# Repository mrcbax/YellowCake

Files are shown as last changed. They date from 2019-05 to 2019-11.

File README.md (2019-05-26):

YellowCake Logo

# YellowCake

YellowCake is a UMW CPSC 491 project to create an open source, inexpensive, small footprint, single board, POSIX computer. YellowCake will be similar to a Raspberry Pi. The primary goal of the YellowCake project is learning. A secondary goal is to create a product that is used by others.

The members of the YellowCake team are the following.
- Gusty Cooper - faculty sponsor
- Chad Baxter - student researcher
- Collin Mistr - student researcher

Gusty is an experienced software developer and systems engineer. Chad and Collin are talented computer science students with lots of experience in electronic board design. They have designed several boards that fix problems in various MacBook computers. Their design solutions included board layout and subsequent manufacture by a foundry. Collin and Chad are selling their MacBook solutions on Ebay. A few of of their solutions are described at: 

- https://computeco.de/DyingLight
- https://computeco.de/MuxHat

## YellowCake Executive Summary

YellowCake is a research project to create an open source, single board computer similar to a Raspberry Pi. Chad and Collin will learn the fundamentals of building a computer, which include selecting a form factor of the board, selecting electronic components for a computer, designing communication among components, layout components on the board, printing the board, assembling a computer on the board, testing the computer, and establishing a LINUX operating system on the computer. The following is a picture of a Raspberry Pi single board computer.

## YellowCake Goals

YellowCake is a three credit CPSC 491, which occurs during Fall 2019. The goals for YellowCake are the following.
- Provide an environment in which Chad and Collin can significantly increase their CPSC skills and knowledge as related to computer architecture, design of single board computers, integration of electronics on single board computers, testing single board computers, and hosting and OS on single board computers.
- Complete the design YellowCake - the design is to be documented as open source.
- Complete the YellowCake board layout in a manufacturing format using the board CAD software KiCad: http://kicad-pcb.org/ - the layout is to be documented as open source.
- Complete a prototype of YellowCake - follow the process in YellowCake Design and Development Process to implement a prototype that demonstrates the design.

## YellowCake Prework

During Spring 2019, the YellowCake team will meet periodically to discuss the project, make preliminary decisions, define the parameters for CPSC 491 YellowCake, and submit funding requests. 
YellowCake Design Parameters
We have begun preliminary design, creating various design parameters. Design parameters are subject to change. The design parameters defined thus far are the following.
- YellowCake board.
  - Footprint will be small similar in size to Raspberry Pi.
  - YellowCake board footprint will adhere to a standard. The following are candidates.
     - PCI / 104 - Express:  https://pc104.org/hardware-specifications/pc104/
     - Intel NUC - https://www.intel.com/content/www/us/en/support/articles/000005545/mini-pcs.html
     - Pico-ITX - https://www.viatech.com/en/boards/pico-itx/ 
- YellowCake CPU Selection. We have had various ideas for YellowCake CPU. The primary option is to use an Intel family chip, which provide a large selection of LINUX operating systems. A design consideration is to select a CPU chip that is approximately $50. The following link shows several Intel options.
https://www.mouser.com/Semiconductors/Embedded-Processors-Controllers/CPU-Central-Processing-Units/_/N-ba96s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|0

Some specific ideas we have considered are the following:
- Idea 1: Intel M series. The availability of Intel M chipsets may make the cost prohibitive.
- Idea 3: Intel Atom
- Idea 2: RISC-V. The availability of RISC-V chipsets may make the cost prohibitive.

YellowCake main memory. 
- Will be LPDDR3. DDR4 is newer and faster, but it costs significantly more than DDR3.

YellowCake secondary storage
- Will be eMMC technology.

YellowCake primary bus connecting CPU, Memory, and other devices 
- Will be determined.
YellowCake I/O
- USB-C NO: Atom does not support USB-C.YellowCake will include 1 USB-C port (if cpu choice supports it).
- USB-3:YellowCake will include 2 USB-3 ports.
- HDMI: YellowCake will include 1 HDMI port.
- WiFI: YellowCake will include wireless (a/b/g/n).
- Bluetooth: YellowCake will include bluetooth.

## YellowCake Design and Development Process

The YellowCake high-level design and development process (to be practiced in Fall 2019) consists of several cycles of design, produce, and test. The cycles continue until the final YellowCake product is created or funding diminishes. More details of design, produce, and test are the following.
- Design a rendition of the board.
- Submit the design to a foundry.
- Receive the board.
- Apply the components to the board.
- Test the board. 

## YellowCake Budget

We expect up to four iterations of the design process to achieve the final design. Total cost of the project is estimated to be $1000, which is $250 per design iteration. The detailed estimated cost of each design iteration is as follows.
- $75 - pay foundry to print the board.
- $50 - CPU SOC
- $25 - Memory components (BGA LPDDR3 4GB)
- $100 - support components (resistors, capacitors, connectors, ICs, ports,
headers, etc.)

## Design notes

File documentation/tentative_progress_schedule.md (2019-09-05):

# YellowCake Schedule

## September

- 9/4 - Initial Parts List
- 9/6 2pm - Visit Colonial Circuits
- 9/11 - Parts Ordered
- 9/25 - Begin writing report
- 9/30 - Initial Board Layout submitted

## October

- 10/9 - Parts placed on initial board layout
- 10/9 - Trouble shoot initial board and parts
- 10/16 - Second Board Layout submitted
- 10/23 - Update report
- 10/20 - Parts placed on second board layout

## November

- 11/6 - Trouble shoot second board and parts
- 11/8 - Third board layout submitted
- 11/13 - Finalize report
- 11/20 - Parts placed on third board layout
- 11/27 - Trouble shoot third board and parts

## December

- 12/4 - OS Running

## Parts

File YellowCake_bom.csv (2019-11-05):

Reference | Quantity | Value | Footprint | Datasheet | Type | Rating | Price Per Unit | Net | Notes
C1 C14 C11 C12 C9 C18 C30 C21 C34 C55 C58 C73 C75 C60 C67 C69 C74 C68 C72 C71 C70 C83 | 22 | 0.1uF | Capacitor_SMD:C_0603_1608Metric | ~ |  |  | $0.01 | $0.22
C22 C19 | 2 | 330pF | Capacitor_SMD:C_0603_1608Metric | ~ |  |  | $0.01 | $0.02
C23 C20 | 2 | 0.01uF | Capacitor_SMD:C_0603_1608Metric | ~ |  |  | $0.01 | $0.02
C25 | 1 | 470pF | Capacitor_SMD:C_0603_1608Metric | ~ |  |  | $0.01 | $0.01
C26 | 1 | 68pF | Capacitor_SMD:C_0603_1608Metric | ~ |  |  | $0.01 | $0.01
C27 | 1 | 220pF | Capacitor_SMD:C_0603_1608Metric | ~ |  |  | $0.01 | $0.01
C28 C24 | 2 | 560pF | Capacitor_SMD:C_0603_1608Metric | ~ |  |  | $0.01 | $0.02
C29 | 1 | 33pF | Capacitor_SMD:C_0603_1608Metric | ~ |  |  | $0.01 | $0.01
C32 C35 C37 C61 C66 | 5 | 1.0uF | Capacitor_SMD:C_0603_1608Metric | ~ |  |  | $0.01 | $0.05
C33 C17 C31 C16 | 4 | 1000pF | Capacitor_SMD:C_0603_1608Metric | ~ |  |  | $0.01 | $0.04
C39 C38 C36 C64 | 4 | 0.22uF | Capacitor_SMD:C_0603_1608Metric | ~ |  |  | $0.01 | $0.04
C4 C5 | 2 | 2.2uF | Capacitor_SMD:C_0603_1608Metric | ~ | CERM_LESR |  | $0.05 | $0.10
C41 C40 | 2 | 2200pF | Capacitor_SMD:C_0603_1608Metric | ~ |  |  | $0.01 | $0.02
C43 C42 | 2 | 0.047uF | Capacitor_SMD:C_0603_1608Metric | ~ |  |  | $0.01 | $0.02
C47 C45 C46 C44 C49 C48 | 6 | 0.033uF | Capacitor_SMD:C_0603_1608Metric | ~ |  |  | $0.01 | $0.06
C50 | 1 | 0.1uF |  | ~ |  |  | $0.01 | $0.01
C51 | 1 | 4.7uF |  | ~ |  |  | $0.01 | $0.01
C52 C53 | 2 | 10uF |  | ~ |  |  | $0.01 | $0.02
C54 | 1 | 8200pF | Resistor_SMD:R_0603_1608Metric | ~ |  | 1000v | $0.01 | $0.01
C56 C57 C59 C62 C63 C76 C77 C79 C81 C82 | 10 | 22uF | Capacitor_SMD:C_0603_1608Metric | ~ |  |  | $0.01 | $0.10
C6 C2 C3 | 3 | 1uF | Capacitor_SMD:C_0603_1608Metric | ~ |  |  | $0.01 | $0.03
C7 C10 | 2 | 10uF | Capacitor_Tantalum_SMD:CP_EIA-2012-15_AVX-P | ~ | TANT |  | $0.05 | $0.10
C8 C13 C15 C78 C80 C65 | 6 | 10uF | Capacitor_SMD:C_0603_1608Metric | ~ |  |  | $0.01 | $0.06
D1 | 1 | BAT54A | Package_TO_SOT_SMD:SOT-23 | http://www.diodes.com/_files/datasheets/ds11005.pdf |  |  | $0.10 | $0.10
D2 D3 | 2 | BAV99S | Package_TO_SOT_SMD:SOT-363_SC-70-6 | https://assets.nexperia.com/documents/data-sheet/BAV99_SER.pdf |  |  | $0.40 | $0.80
J1 | 1 | HDMI_A |  | https://en.wikipedia.org/wiki/HDMI |  |  | $0.00 | $0.00 | Purchased
J2 | 1 | SODIMM-200 |  |  |  |  | $0.00 | $0.00 | Purchased
J3 | 1 | Micro_SD_Card |  | http://katalog.we-online.de/em/datasheet/693072010801.pdf |  |  | $0.00 | $0.00 | Purchased
J4 | 1 | Conn_Coaxial_Power |  | ~ |  |  | $0.00 | $0.00 | Purchased
L1 | 1 | 220Ohm | Inductor_SMD:L_0603_1608Metric | ~ |  |  | $0.05 | $0.05
L2 | 1 | FB_220R_2.2A | Inductor_SMD:L_0603_1608Metric | ~ |  |  | $0.05 | $0.05
L5 L6 L3 L4 | 4 | FB_120R_3A | Inductor_SMD:L_0603_1608Metric | ~ |  |  | $0.05 | $0.20
L7 | 1 | PIND-2.2U-8A | Inductor_SMD:L_0603_1608Metric | ~ |  |  | $0.05 | $0.05
R1 R2 | 2 | 2.2kOhm | Resistor_SMD:R_0603_1608Metric | ~ |  |  | $0.01 | $0.02
R13 | 1 | 2.7KOhm | Resistor_SMD:R_0603_1608Metric | ~ |  |  | $0.01 | $0.01
R14 R15 R11 R12 | 4 | 10Ohm | Resistor_SMD:R_0603_1608Metric | ~ |  |  | $0.01 | $0.04
R16 | 1 | 2.32KOhm | Resistor_SMD:R_0603_1608Metric | ~ |  |  | $0.01 | $0.01
R18 | 1 | 2.43KOhm | Resistor_SMD:R_0603_1608Metric | ~ |  |  | $0.01 | $0.01
R19 R17 | 2 | 200Ohm | Resistor_SMD:R_0603_1608Metric | ~ |  |  | $0.01 | $0.02
R21 | 1 | 2.21KOhm | Resistor_SMD:R_0603_1608Metric | ~ |  |  | $0.01 | $0.01
R23 R20 R27 | 3 | 80.6KOhm | Resistor_SMD:R_0603_1608Metric | ~ |  |  | $0.01 | $0.03
R25 R24 R22 | 3 | 69.8Ohm | Resistor_SMD:R_0603_1608Metric | ~ |  |  | $0.01 | $0.03
R26 | 1 | 169KOhm | Resistor_SMD:R_0603_1608Metric | ~ |  |  | $0.01 | $0.01
R30 R28 | 2 | 1.91KOhm | Resistor_SMD:R_0603_1608Metric | ~ |  |  | $0.01 | $0.02
R31 R29 | 2 | 6.98KOhm | Resistor_SMD:R_0603_1608Metric | ~ |  |  | $0.01 | $0.02
R33 | 1 | 16.9Ohm | Resistor_SMD:R_0603_1608Metric | ~ |  |  | $0.01 | $0.01
R34 R32 R36 R9 R10 R7 R8 R43 R42 R38 R39 | 11 | 0Ohm | Resistor_SMD:R_0603_1608Metric | ~ |  |  | $0.01 | $0.11
R35 | 1 | 20Ohm | Resistor_SMD:R_0603_1608Metric | ~ |  |  | $0.01 | $0.01
R37 | 1 | 1KOhm | Resistor_SMD:R_0603_1608Metric | ~ |  |  | $0.01 | $0.01
R4 R3 R75 R74 R73 R72 R71 R70 | 8 | 33Ohm | Resistor_SMD:R_0603_1608Metric | ~ |  |  | $0.01 | $0.08
R40 | 1 | 1Ohm | Resistor_SMD:R_0603_1608Metric | ~ |  |  | $0.01 | $0.01
R41 R48 | 2 | 18.7KOhm | Resistor_SMD:R_0603_1608Metric | ~ |  |  | $0.01 | $0.02
R44 R47 | 2 | 3.83KOhm | Resistor_SMD:R_0603_1608Metric | ~ |  |  | $0.01 | $0.02
R45 R46 | 2 | NTC-470KOhm | Resistor_SMD:R_0603_1608Metric | ~ |  |  | $0.01 | $0.02
R5 | 1 | 37.4KOhm | Resistor_SMD:R_0603_1608Metric | ~ |  |  | $0.01 | $0.01
R50 R49 | 2 | 649Ohm | Resistor_SMD:R_0603_1608Metric | ~ |  |  | $0.01 | $0.02
R51 | 1 | 2.67KOhm | Resistor_SMD:R_0603_1608Metric | ~ |  |  | $0.01 | $0.01
R54 R53 | 2 | 11KOhm | Resistor_SMD:R_0603_1608Metric | ~ |  |  | $0.01 | $0.02
R56 | 1 | 2.55KOhm | Resistor_SMD:R_0603_1608Metric | ~ |  |  | $0.01 | $0.01
R57 R52 | 2 | 2.61KOhm | Resistor_SMD:R_0603_1608Metric | ~ |  |  | $0.01 | $0.02
R58 R55 | 2 | NTC-10KOhm | Resistor_SMD:R_0603_1608Metric | ~ |  |  | $0.01 | $0.02
R59 R60 R67 | 3 | 0Ohm | Resistor_SMD:R_0603_1608Metric | ~ |  |  | $0.01 | $0.03
R6 | 1 | 12.1KOhm | Resistor_SMD:R_0603_1608Metric | ~ |  |  | $0.01 | $0.01
R61 | 1 | 2.2KOhm | Resistor_SMD:R_0603_1608Metric | ~ |  |  | $0.01 | $0.01
R62 | 1 | 2.2KOkm | Resistor_SMD:R_0603_1608Metric | ~ |  |  | $0.01 | $0.01
R63 R64 R65 R66 R68 | 5 | 10KOhm | Resistor_SMD:R_0603_1608Metric | ~ |  |  | $0.01 | $0.05
R69 | 1 | 100KOhm | Resistor_SMD:R_0603_1608Metric | ~ |  |  | $0.01 | $0.01
R76 R77 R78 R79 R80 R81 R87 R85 | 8 | 100KOhm | Resistor_SMD:R_0603_1608Metric | ~ |  |  | $0.01 | $0.08
R83 | 1 | 2.2Ohms | Resistor_SMD:R_0603_1608Metric | ~ |  |  | $0.01 | $0.01
R84 R82 | 2 | 499KOhm | Resistor_SMD:R_0603_1608Metric | ~ |  |  | $0.01 | $0.02
R86 | 1 | 4.7Ohm | Resistor_SMD:R_0603_1608Metric | ~ |  |  | $0.01 | $0.01
U1 | 1 | CS4207-CNZ | CIR-QFN-48_6X6 |  |  |  | $10.00 | $10.00
U10 | 1 | atom_F |  |  |  |  | $0.00 | $0.00 | Purchased
U11 | 1 | atom_G |  |  |  |  | $0.00 | $0.00 | Purchased
U12 | 1 | atom_H |  |  |  |  | $0.00 | $0.00 | Purchased
U13 | 1 | atom_I |  |  |  |  | $0.00 | $0.00 | Purchased
U14 | 1 | atom_J |  |  |  |  | $0.00 | $0.00 | Purchased
U15 | 1 | atom_K |  |  |  |  | $0.00 | $0.00 | Purchased
U16 | 1 | atom_L |  |  |  |  | $0.00 | $0.00 | Purchased
U17 | 1 | NB670 |  |  |  |  | $3.00 | $3.00
U18 | 1 | IRF9321 |  |  |  |  | $4.00 | $4.00
U2 | 1 | ISL95837HRZ-T | Package_DFN_QFN:QFN-40-1EP_6x6mm_P0.5mm_EP4.6x4.6mm |  |  |  | $4.00 | $4.00
U3 | 1 | TPD12S016PWR | PW24 |  |  |  | $2.00 | $2.00
U4 | 1 | TPD6E001RSER | TPD6E001RSER:TPD6E001RSER |  |  |  | $0.60 | $0.60
U5 | 1 | atom_A |  |  |  |  | $0.00 | $0.00 | Purchased
U6 | 1 | atom_B |  |  |  |  | $0.00 | $0.00 | Purchased
U7 | 1 | atom_C |  |  |  |  | $0.00 | $0.00 | Purchased
U8 | 1 | atom_D |  |  |  |  | $0.00 | $0.00 | Purchased
U9 | 1 | atom_E |  |  |  |  | $0.00 | $0.00 | Purchased
_ | _ | _ | _ | _ | Overrun Buffer | $20.00 | Total | $46.71

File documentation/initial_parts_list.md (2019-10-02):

# Initial Parts List

## Main Components

- [x2] Atom e3826 or equivalent: [https://www.mouser.com/ProductDetail/Intel/FH8065301542213-S-R1RC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](https://www.mouser.com/ProductDetail/Intel/FH8065301542213-S-R1RC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)
- [x8] SODIMM slots: [https://www.mouser.com/ProductDetail/TE-Connectivity-AMP/2-2013022-1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](https://www.mouser.com/ProductDetail/TE-Connectivity-AMP/2-2013022-1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)
- [x4] Micro-SD slots: [https://www.mouser.com/ProductDetail/Molex/104031-0811?qs=sGAEpiMZZMvlX3nhDDO4APpvzJC5rjSIQk8rK5oWGmY%3D](https://www.mouser.com/ProductDetail/Molex/104031-0811?qs=sGAEpiMZZMvlX3nhDDO4APpvzJC5rjSIQk8rK5oWGmY%3D)
- [x4] PCI/104 Express headers: [https://www.mouser.com/ProductDetail/Samtec/ASP-129637-03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](https://www.mouser.com/ProductDetail/Samtec/ASP-129637-03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)
- [x2] intel hdaudio codec [https://www.mouser.com/ProductDetail/Cirrus-Logic/CS4207-CNZ?qs=sGAEpiMZZMtq3QB8qGen7SBsPebhPp2DIspEOUgddMo%3D](https://www.mouser.com/ProductDetail/Cirrus-Logic/CS4207-CNZ?qs=sGAEpiMZZMtq3QB8qGen7SBsPebhPp2DIspEOUgddMo%3D)

## I/O Components

- [x4] THT HDMI ports: [https://www.mouser.com/ProductDetail/Amphenol-FCI/10029449-111RLF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](https://www.mouser.com/ProductDetail/Amphenol-FCI/10029449-111RLF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)
- [x4] THT Double USB ports: [https://www.mouser.com/ProductDetail/Kycon/KUSBX-AS1N9-1-BL30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](https://www.mouser.com/ProductDetail/Kycon/KUSBX-AS1N9-1-BL30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)
- [x4] THT Ethernet ports: [https://www.mouser.com/ProductDetail/Amphenol-Commercial-Products/RJE03-188-0110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](https://www.mouser.com/ProductDetail/Amphenol-Commercial-Products/RJE03-188-0110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)
- [x4] THT Audio jack: (HAVE)
- [x4] THT DC plugs: [https://www.mouser.com/ProductDetail/CUI/PJ-079BH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](https://www.mouser.com/ProductDetail/CUI/PJ-079BH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)
- [x4] THT eSATA ports: [https://www.mouser.com/ProductDetail/Amphenol-Commercial-Products/G091231304LF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](https://www.mouser.com/ProductDetail/Amphenol-Commercial-Products/G091231304LF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)

## Passive Components (On hold for datasheet reading).

- [x100] 0604m 0Ohm resistors

TOTALS: $223.14 + $9.79 S+H

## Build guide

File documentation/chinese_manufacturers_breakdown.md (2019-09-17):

# Chinese Manufacturers Breakdown

## JLCPCB

JLCPCB is a PCB manufacturing facility based in China.

Given the specifications of our board design, they have quoted us a price as follows:

$28 for board production (run of 5, which is their minimum quantity)
$17 for shipping via DHL

Lead time: up to 12 hours
Production time: 3-4 days
Shipping time: 2-4 business days via DHL

Payments can be made with all major cards (Visa, MasterCard, and AmEx), as well as PayPal and JLC’s custom “JPay”.

More info can be found at https://support.jlcpcb.com

## PCBWay

PCBWay.com offers near identical technical abilities as JLCPCB.com. Where they differ is in pricing and special offers. Through PCBWay it is possible to get a discount if your project is open source. The catch to this is that they will determine the discount at time of purchase.

For our planned design PCBWay will charge the following:

$49 for board production.
$17 for shipping.
($66 total)

Production lead time: 12 hours
Production time: 48 hours
Shipping time: 2-4 days (highly variable sometimes as much as a week)

They take payment from all major cards (Visa, Mastercard, Amex). They also accept payment from PayPal, AliPay, OKPay, and other popular online payment options.

We personally have seen discounts in the order of 10-15% off by "partnering with pcbway" on an open source project.

More info can be found at the following links:

https://www.pcbway.com/about.html About the company.
https://www.pcbway.com/sponsor.html Discount for student sponsorships.

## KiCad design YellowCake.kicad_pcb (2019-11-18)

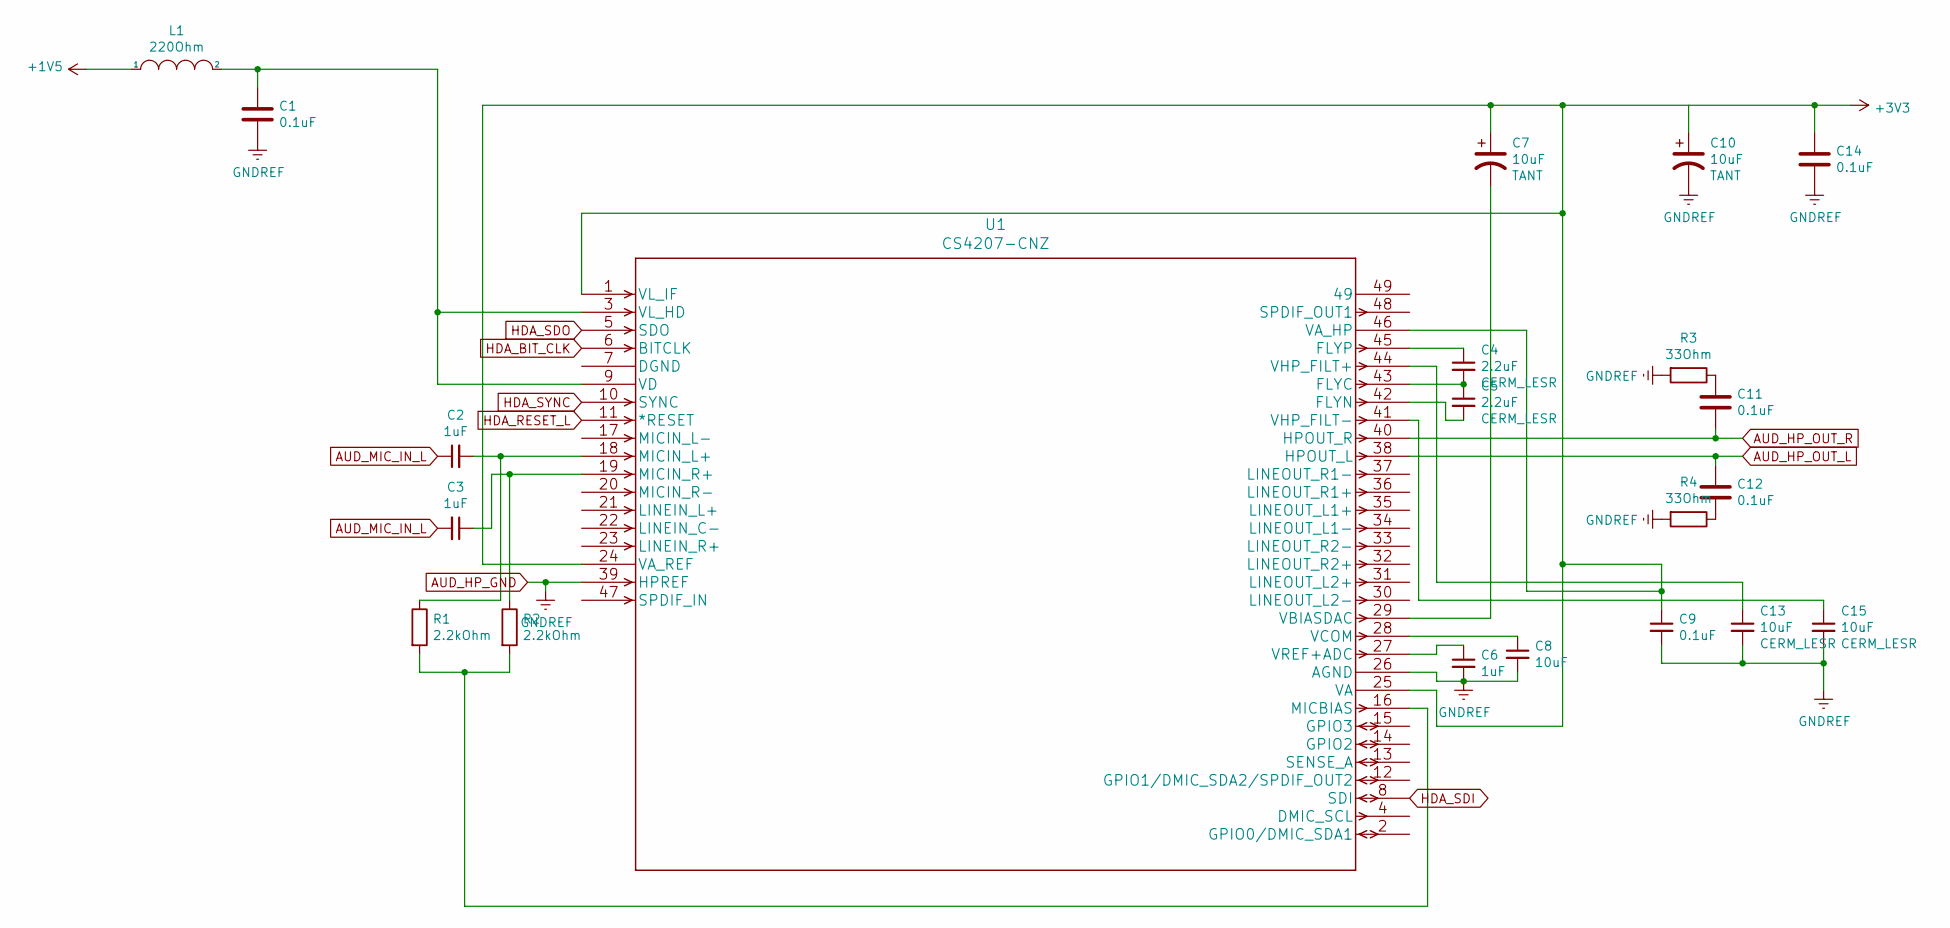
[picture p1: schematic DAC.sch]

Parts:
C1, C9, C11, C12, C14: 0.1uF; C_0603_1608Metric
C2, C3, C6: 1uF; C_0603_1608Metric
C4, C5: 2.2uF; C_0603_1608Metric
C7, C10: 10uF; CP_EIA-2012-15_AVX-P
C8, C13, C15: 10uF; C_0603_1608Metric
L1: 220Ohm; L_0603_1608Metric
R1, R2: 2.2kOhm; R_0603_1608Metric
R3, R4: 33Ohm; R_0603_1608Metric
U1: CS4207-CNZ

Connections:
+1V5: L1.1
+3V3: C7.1, C9.1, C14.1, U1.1 (VL_IF), U1.24 (VA_REF), U1.25 (VA), U1.46 (VA_HP); also elsewhere on the board
AUD_HP_GND: C1.2, C6.2, C8.2, C9.2, C10.2, C13.2, C14.2, C15.2, R3.2, R4.2, U1.26 (AGND), U1.39 (HPREF)
AUD_HP_OUT_L: C12.1, U1.38 (HPOUT_L)
AUD_HP_OUT_R: C11.2, U1.40 (HPOUT_R)
AUD_MIC_IN_L: C2.1, C3.2
HDA_BIT_CLK: U1.6 (BITCLK)
HDA_RESET_L: U1.11 (*RESET)
HDA_SDI: U1.8 (SDI)
HDA_SDO: U1.5 (SDO)
HDA_SYNC: U1.10 (SYNC)
unnamed: C1.1, L1.2, U1.3 (VL_HD), U1.9 (VD)
unnamed: C2.2, R1.1, U1.18 (MICIN_L+)
unnamed: C3.1, R2.1, U1.19 (MICIN_R+)
unnamed: C4.1, U1.45 (FLYP)
unnamed: C4.2, C5.1, U1.43 (FLYC)
unnamed: C5.2, U1.42 (FLYN)
unnamed: C6.1, U1.27 (VREF+ADC)
unnamed: C7.2, U1.29 (VBIASDAC)
unnamed: C8.1, U1.28 (VCOM)
unnamed: C11.1, R3.1
unnamed: C12.2, R4.1
unnamed: C13.1, U1.44 (VHP_FILT+)
unnamed: C15.1, U1.41 (VHP_FILT-)
unnamed: R1.2, R2.2, U1.16 (MICBIAS)

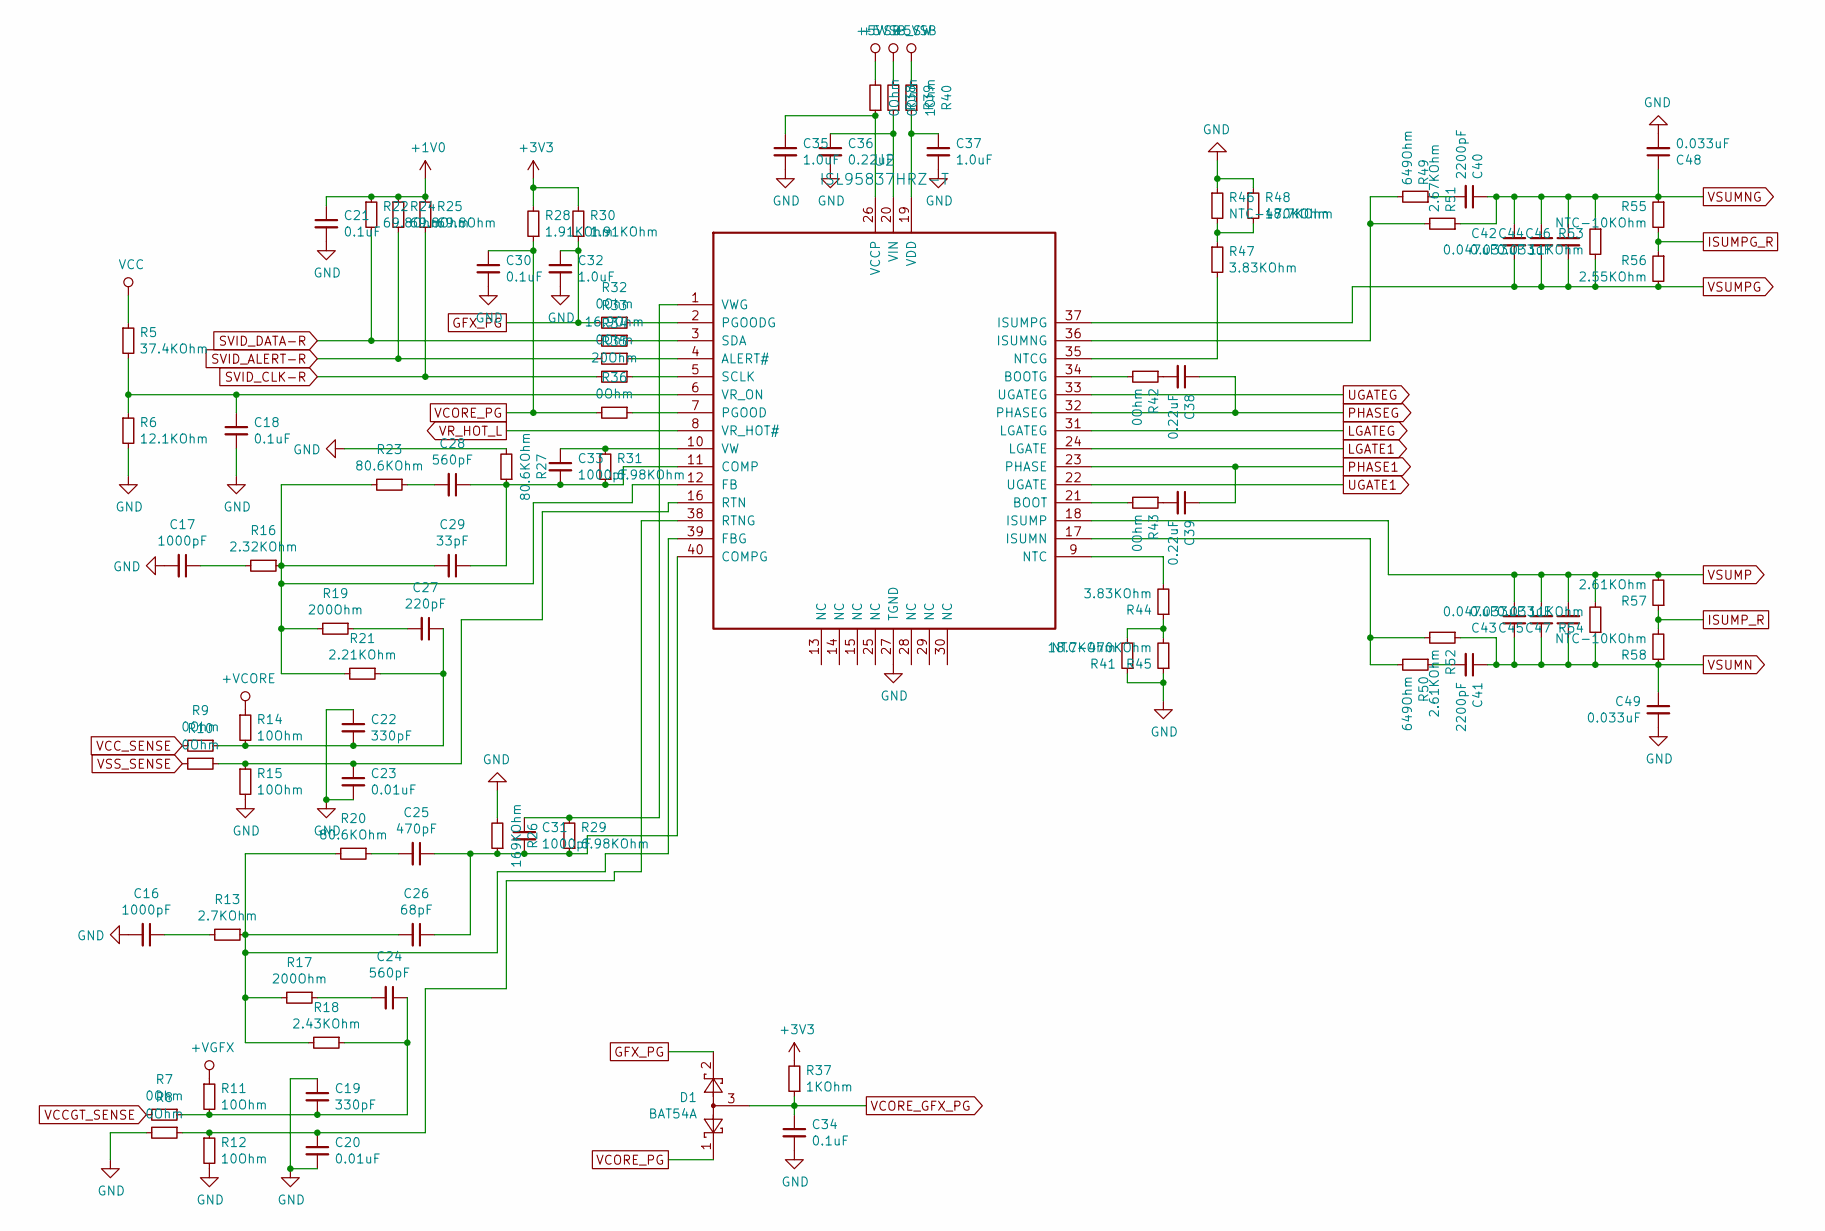
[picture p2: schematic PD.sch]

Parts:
C16, C17, C31, C33: 1000pF; C_0603_1608Metric
C18, C21, C30, C34: 0.1uF; C_0603_1608Metric
C19, C22: 330pF; C_0603_1608Metric
C20, C23: 0.01uF; C_0603_1608Metric
C24, C28: 560pF; C_0603_1608Metric
C25: 470pF; C_0603_1608Metric
C26: 68pF; C_0603_1608Metric
C27: 220pF; C_0603_1608Metric
C29: 33pF; C_0603_1608Metric
C32, C35, C37: 1.0uF; C_0603_1608Metric
C36, C38, C39: 0.22uF; C_0603_1608Metric
C40, C41: 2200pF; C_0603_1608Metric
C42, C43: 0.047uF; C_0603_1608Metric
C44, C45, C46, C47, C48, C49: 0.033uF; C_0603_1608Metric
D1: BAT54A; SOT-23
R5: 37.4KOhm; R_0603_1608Metric
R6: 12.1KOhm; R_0603_1608Metric
R7, R8, R9, R10, R32, R34, R36, R38, R39, R42, R43: 0Ohm; R_0603_1608Metric
R11, R12, R14, R15: 10Ohm; R_0603_1608Metric
R13: 2.7KOhm; R_0603_1608Metric
R16: 2.32KOhm; R_0603_1608Metric
R17, R19: 200Ohm; R_0603_1608Metric
R18: 2.43KOhm; R_0603_1608Metric
R20, R23, R27: 80.6KOhm; R_0603_1608Metric
R21: 2.21KOhm; R_0603_1608Metric
R22, R24, R25: 69.8Ohm; R_0603_1608Metric
R26: 169KOhm; R_0603_1608Metric
R28, R30: 1.91KOhm; R_0603_1608Metric
R29, R31: 6.98KOhm; R_0603_1608Metric
R33: 16.9Ohm; R_0603_1608Metric
R35: 20Ohm; R_0603_1608Metric
R37: 1KOhm; R_0603_1608Metric
R40: 1Ohm; R_0603_1608Metric
R41, R48: 18.7KOhm; R_0603_1608Metric
R44, R47: 3.83KOhm; R_0603_1608Metric
R45, R46: NTC-470KOhm; R_0603_1608Metric
R49, R50: 649Ohm; R_0603_1608Metric
R51: 2.67KOhm; R_0603_1608Metric
R52, R57: 2.61KOhm; R_0603_1608Metric
R53, R54: 11KOhm; R_0603_1608Metric
R55, R58: NTC-10KOhm; R_0603_1608Metric
R56: 2.55KOhm; R_0603_1608Metric
U2: ISL95837HRZ-T; QFN-40-1EP_6x6mm_P0.5mm_EP4.6x4.6mm

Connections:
+1V0: C21.1, R22.1, R24.1, R25.1
+3V3: R28.2, R30.2, R37.2; also elsewhere on the board
+5VSB: R38.2, R40.2; also elsewhere on the board
+5VSB_SW: R39.2; also elsewhere on the board
+VCORE: R14.1; also elsewhere on the board
+VGFX: R11.1; also elsewhere on the board
GFX_PG: C32.1, D1.2, R30.1, R32.2
GND: C16.2, C17.2, C18.2, C19.1, C20.2, C21.2, C22.1, C23.2, C30.2, C32.2, C34.2, C35.2, C36.2, C37.2, C48.2, C49.2, R6.2, R8.2, R12.2, R15.2, R26.2, R27.2, R41.1, R45.1, R46.1, R48.1, U2.27 (TGND); also elsewhere on the board
ISUMPG_R: R55.2, R56.1
ISUMP_R: R57.1, R58.2
LGATE1: U2.24 (LGATE); also elsewhere on the board
LGATEG: U2.31 (LGATEG); also elsewhere on the board
unnamed: C16.1, R13.2
unnamed: C17.1, R16.2
unnamed: C18.1, R5.2, R6.1, U2.6 (VR_ON)
unnamed: C19.2, C24.1, R7.1, R11.2, R18.1
unnamed: C20.1, R8.1, R12.1, U2.38 (RTNG)
unnamed: C22.2, C27.1, R9.1, R14.2, R21.1
unnamed: C23.1, R10.1, R15.1, U2.16 (RTN)
unnamed: C24.2, R17.1
unnamed: C25.1, C26.1, C31.2, R26.1, R29.1, U2.40 (COMPG)
unnamed: C25.2, R20.1
unnamed: C26.2, R13.1, R17.2, R18.2, R20.2, U2.39 (FBG)
unnamed: C27.2, R19.1
unnamed: C28.1, C29.1, C33.2, R27.1, R31.1, U2.11 (COMP)
unnamed: C28.2, R23.1
unnamed: C29.2, R16.1, R19.2, R21.2, R23.2, U2.12 (FB)
unnamed: C31.1, R29.2, U2.1 (VWG)
unnamed: C33.1, R31.2, U2.10 (VW)
unnamed: C35.1, R38.1, U2.26 (VCCP)
unnamed: C36.1, R39.1, U2.20 (VIN)
unnamed: C37.1, R40.1, U2.19 (VDD)
unnamed: C38.2, R42.1
unnamed: C39.2, R43.1
unnamed: C40.2, R49.1
unnamed: C41.2, R50.1
unnamed: R32.1, U2.2 (PGOODG)
unnamed: R33.1, U2.3 (SDA)
unnamed: R34.1, U2.4 (ALERT#)
unnamed: R35.1, U2.5 (SCLK)
unnamed: R36.1, U2.7 (PGOOD)
unnamed: R41.2, R44.1, R45.2
unnamed: R42.2, U2.34 (BOOTG)
unnamed: R43.2, U2.21 (BOOT)
unnamed: R44.2, U2.9 (NTC)
unnamed: R46.2, R47.1, R48.2
unnamed: R47.2, U2.35 (NTCG)
unnamed: R49.2, R51.2, U2.36 (ISUMNG)
unnamed: R50.2, R52.2, U2.17 (ISUMN)
PHASE1: C39.1, U2.23 (PHASE); also elsewhere on the board
PHASEG: C38.1, U2.32 (PHASEG); also elsewhere on the board
SVID_ALERT-R: R24.2, R34.2
SVID_CLK-R: R25.2, R35.2
SVID_DATA-R: R22.2, R33.2
UGATE1: U2.22 (UGATE); also elsewhere on the board
UGATEG: U2.33 (UGATEG); also elsewhere on the board
VCC: R5.1; also elsewhere on the board
VCCGT_SENSE: R7.2
VCC_SENSE: R9.2
VCORE_GFX_PG: C34.1, D1.3, R37.1; also elsewhere on the board
VCORE_PG: C30.1, D1.1, R28.1, R36.2
VR_HOT_L: U2.8 (VR_HOT#); also elsewhere on the board
VSS_SENSE: R10.2
VSUMN: C41.1, C43.1, C45.1, C47.1, C49.1, R52.1, R54.1, R58.1; also elsewhere on the board
VSUMNG: C40.1, C42.1, C44.1, C46.1, C48.1, R51.1, R53.1, R55.1; also elsewhere on the board
VSUMP: C43.2, C45.2, C47.2, R54.2, R57.2, U2.18 (ISUMP); also elsewhere on the board
VSUMPG: C42.2, C44.2, C46.2, R53.2, R56.2, U2.37 (ISUMPG); also elsewhere on the board

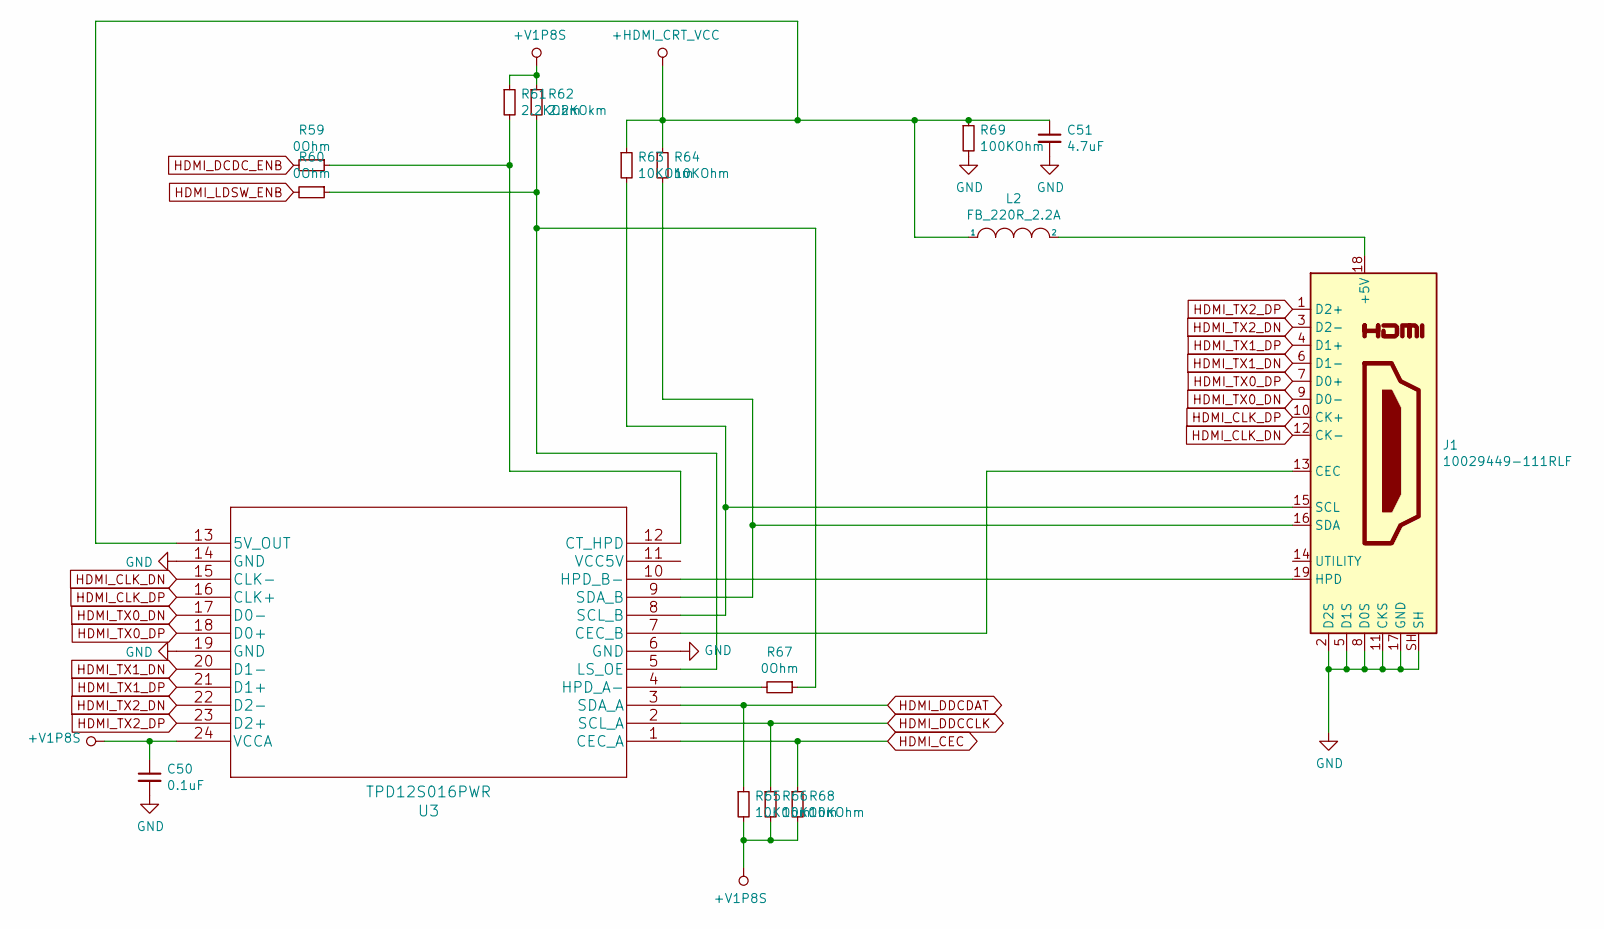
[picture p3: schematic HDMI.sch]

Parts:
C50: 0.1uF; C_0603_1608Metric
C51: 4.7uF; C_0603_1608Metric
J1: 10029449-111RLF
L2: FB_220R_2.2A; L_0603_1608Metric
R59, R60, R67: 0Ohm; R_0603_1608Metric
R61: 2.2KOhm; R_0603_1608Metric
R62: 2.2KOkm; R_0603_1608Metric
R63, R64, R65, R66, R68: 10KOhm; R_0603_1608Metric
R69: 100KOhm; R_0603_1608Metric
U3: TPD12S016PWR

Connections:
+HDMI_CRT_VCC: C51.1, L2.1, R63.1, R64.1, R69.1, U3.13 (5V_OUT)
+V1P8S: C50.1, R61.1, R62.1, R65.2, R66.2, R68.2, U3.24 (VCCA); also elsewhere on the board
GND: C50.2, C51.2, J1.2 (D2S), J1.5 (D1S), J1.8 (D0S), J1.11 (CKS), J1.17 (GND), J1.SH, R69.2, U3.6 (GND), U3.14 (GND), U3.19 (GND); also elsewhere on the board
HDMI_CEC: R68.1, U3.1 (CEC_A)
HDMI_CLK_DN: J1.12 (CK-), U3.15 (CLK-); also elsewhere on the board
HDMI_CLK_DP: J1.10 (CK+), U3.16 (CLK+); also elsewhere on the board
HDMI_DCDC_ENB: R59.2
HDMI_DDCCLK: R66.1, U3.2 (SCL_A); also elsewhere on the board
HDMI_DDCDAT: R65.1, U3.3 (SDA_A); also elsewhere on the board
HDMI_LDSW_ENB: R60.2
HDMI_TX0_DN: J1.9 (D0-), U3.17 (D0-); also elsewhere on the board
HDMI_TX0_DP: J1.7 (D0+), U3.18 (D0+); also elsewhere on the board
HDMI_TX1_DN: J1.6 (D1-), U3.20 (D1-); also elsewhere on the board
HDMI_TX1_DP: J1.4 (D1+), U3.21 (D1+); also elsewhere on the board
HDMI_TX2_DN: J1.3 (D2-), U3.22 (D2-); also elsewhere on the board
HDMI_TX2_DP: J1.1 (D2+), U3.23 (D2+); also elsewhere on the board
unnamed: J1.13 (CEC), U3.7 (CEC_B)
unnamed: J1.15 (SCL), R63.2, U3.8 (SCL_B)
unnamed: J1.16 (SDA), R64.2, U3.9 (SDA_B)
unnamed: J1.18 (+5V), L2.2
unnamed: J1.19 (HPD), U3.10 (HPD_B-)
unnamed: R59.1, R61.2, U3.12 (CT_HPD)
unnamed: R60.1, R62.2, R67.1, U3.5 (LS_OE)
unnamed: R67.2, U3.4 (HPD_A-)

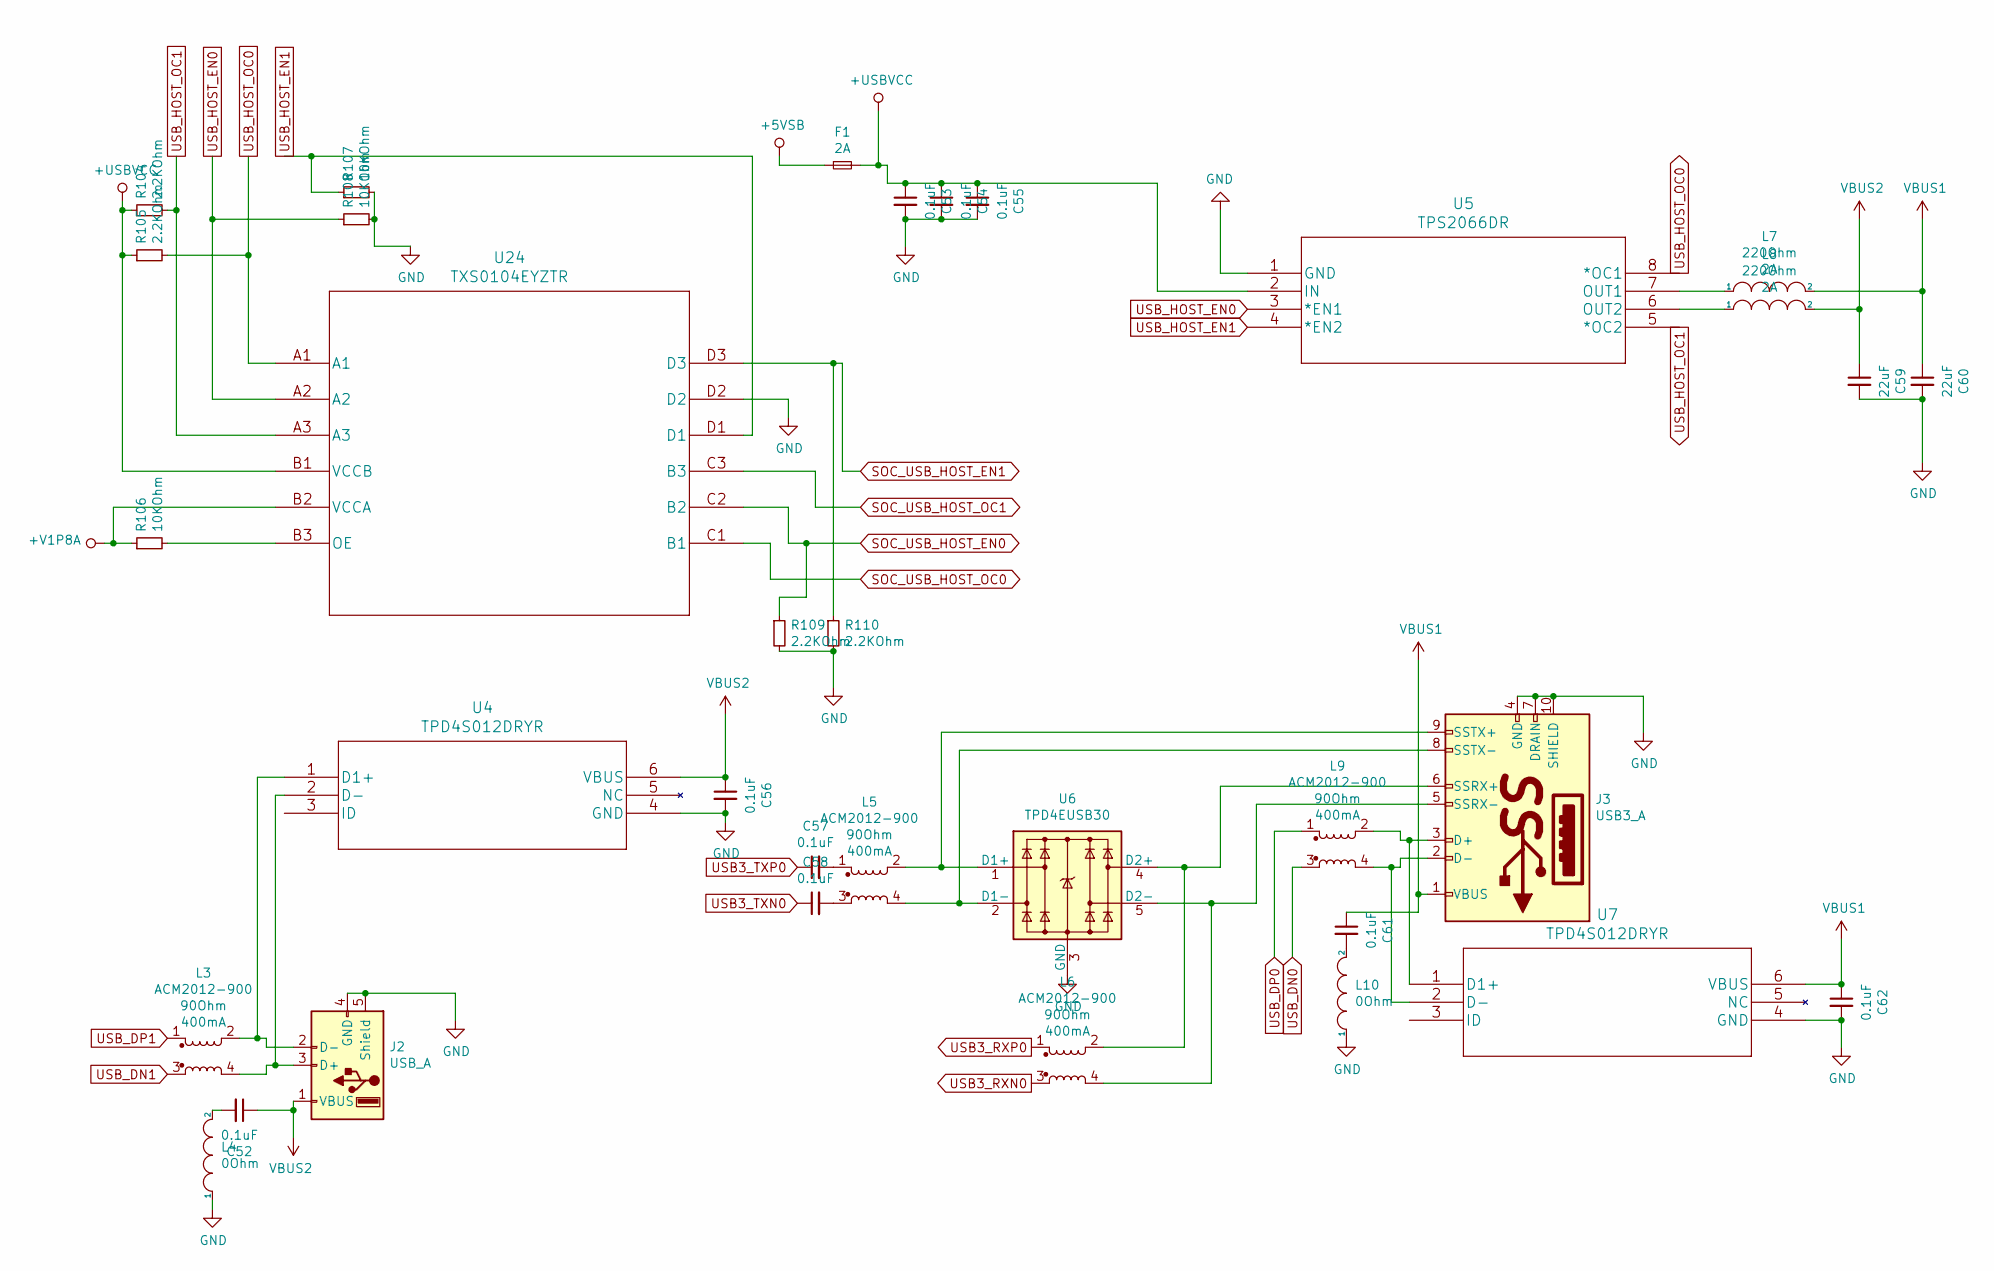
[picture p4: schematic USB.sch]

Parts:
C52, C53, C54, C55, C56, C57, C58, C61, C62: 0.1uF; C_0603_1608Metric
C59, C60: 22uF; C_0603_1608Metric
F1: 2A; Fuse_0603_1608Metric
J2: USB_A; USB_A_CNCTech_1001-011-01101_Horizontal
J3: USB3_A; USB3_A_Molex_48393-001
L3, L5, L6, L9: ACM2012-900; ACM2012-900-2P-T; Rating 400mA
L4, L10: 0Ohm; L_0603_1608Metric
L7, L8: 220Ohm; L_0603_1608Metric
R104, R105, R109, R110: 2.2KOhm; R_0603_1608Metric
R106, R107, R108: 10KOhm; R_0603_1608Metric
U4, U7: TPD4S012DRYR
U5: TPS2066DR
U6: TPD4EUSB30; USON-10_2.5x1.0mm_P0.5mm
U24: TXS0104EYZTR

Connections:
+5VSB: F1.1; also elsewhere on the board
+USBVCC: C53.1, C54.1, C55.1, F1.2, R104.1, R105.1, U5.2 (IN), U24.B1 (VCCB)
+V1P8A: R106.1, U24.B2 (VCCA); also elsewhere on the board
GND: C53.2, C54.2, C55.2, C56.2, C59.2, C60.2, C62.2, J2.4 (GND), J2.5 (Shield), J3.4 (GND), J3.7 (DRAIN), J3.10 (SHIELD), L4.1, L10.1, R107.2, R108.2, R109.2, R110.2, U4.4 (GND), U5.1 (GND), U6.3 (GND), U6.8 (GND), U7.4 (GND), U24.D2; also elsewhere on the board
unnamed: C52.2, L4.2
unnamed: C57.2, L5.1
unnamed: C58.2, L5.3
unnamed: C61.2, L10.2
unnamed: J2.2 (D-), L3.2, U4.1 (D1+)
unnamed: J2.3 (D+), L3.4, U4.2 (D-)
unnamed: J3.2 (D-), L9.4, U7.2 (D-)
unnamed: J3.3 (D+), L9.2, U7.1 (D1+)
unnamed: J3.5 (SSRX-), L6.4, U6.5 (D2-)
unnamed: J3.6 (SSRX+), L6.2, U6.4 (D2+)
unnamed: J3.8 (SSTX-), L5.4, U6.2 (D1-)
unnamed: J3.9 (SSTX+), L5.2, U6.1 (D1+)
unnamed: L7.1, U5.7 (OUT1)
unnamed: L8.1, U5.6 (OUT2)
unnamed: R106.2, U24.B3 (OE)
SOC_USB_HOST_EN0: R109.1, U24.C2 (B2)
SOC_USB_HOST_EN1: R110.1, U24.D3
SOC_USB_HOST_OC0: U24.C1 (B1)
SOC_USB_HOST_OC1: U24.C3 (B3)
USB3_RXN0: L6.3
USB3_RXP0: L6.1
USB3_TXN0: C58.1
USB3_TXP0: C57.1
USB_DN0: L9.3
USB_DN1: L3.3
USB_DP0: L9.1
USB_DP1: L3.1
USB_HOST_EN0: R108.1, U5.3 (*EN1), U24.A2
USB_HOST_EN1: R107.1, U5.4 (*EN2), U24.D1
USB_HOST_OC0: R105.2, U5.8 (*OC1), U24.A1
USB_HOST_OC1: R104.2, U5.5 (*OC2), U24.A3
VBUS1: C60.1, C61.1, C62.1, J3.1 (VBUS), L7.2, U7.6 (VBUS)
VBUS2: C52.1, C56.1, C59.1, J2.1 (VBUS), L8.2, U4.6 (VBUS)

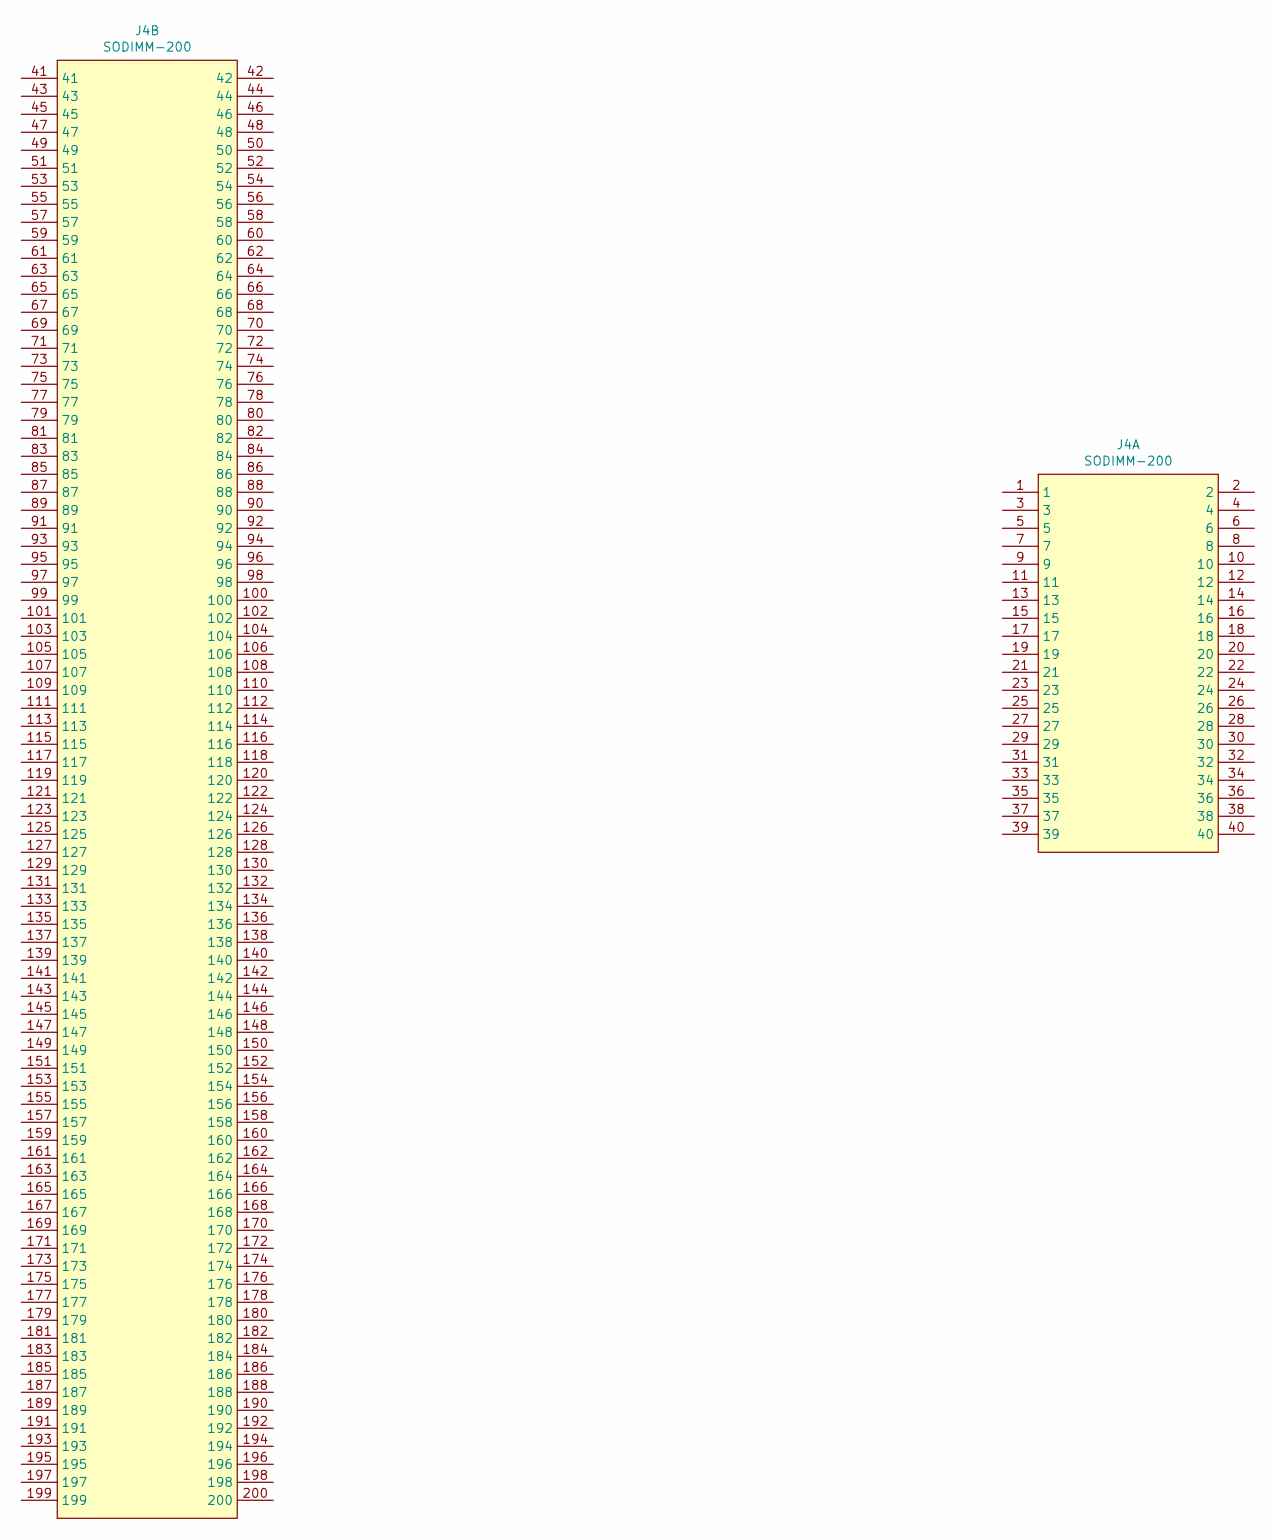
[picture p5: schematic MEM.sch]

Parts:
J4: SODIMM-200; 2013289-1

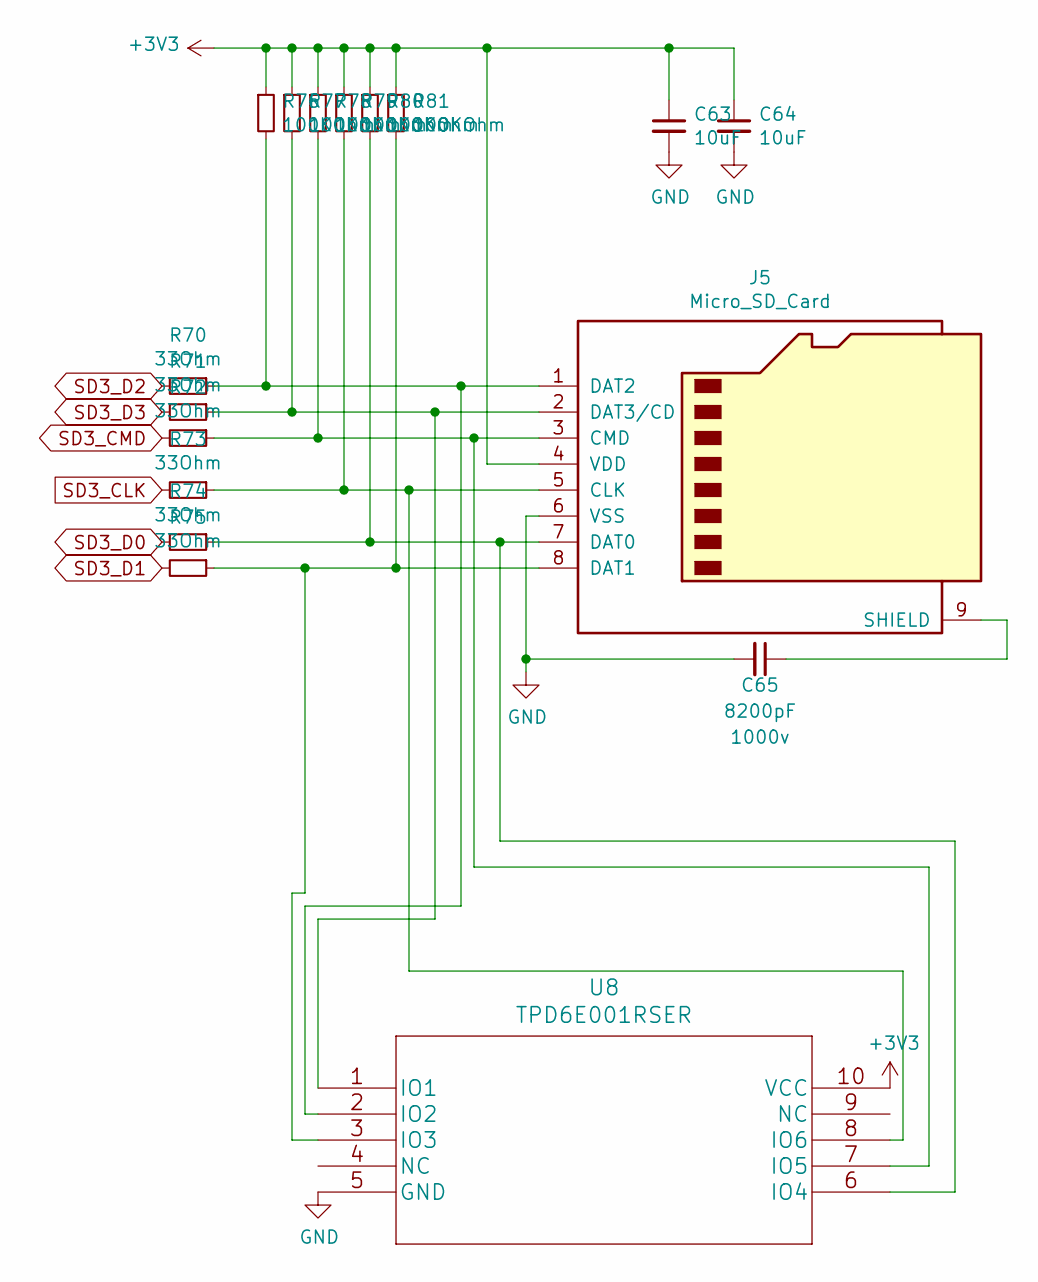
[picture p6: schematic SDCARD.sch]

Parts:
C63, C64: 10uF; C_0603_1608Metric
C65: 8200pF; R_0603_1608Metric; Rating 1000v
J5: Micro_SD_Card; microSD_HC_Hirose_DM3AT-SF-PEJM5
R70, R71, R72, R73, R74, R75: 33Ohm; R_0603_1608Metric
R76, R77, R78, R79, R80, R81: 100KOhm; R_0603_1608Metric
U8: TPD6E001RSER

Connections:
+3V3: C63.1, C64.1, J5.4 (VDD), R76.1, R77.1, R78.1, R79.1, R80.1, R81.1, U8.10 (VCC); also elsewhere on the board
GND: C63.2, C64.2, C65.2, J5.6 (VSS), U8.5 (GND); also elsewhere on the board
unnamed: C65.1, J5.9 (SHIELD)
unnamed: J5.1 (DAT2), R70.1, R76.2, U8.2 (IO2)
unnamed: J5.2 (DAT3/CD), R71.1, R77.2, U8.1 (IO1)
unnamed: J5.3 (CMD), R72.1, R78.2, U8.7 (IO5)
unnamed: J5.5 (CLK), R73.1, R79.2, U8.8 (IO6)
unnamed: J5.7 (DAT0), R74.1, R80.2, U8.6 (IO4)
unnamed: J5.8 (DAT1), R75.1, R81.2, U8.3 (IO3)
SD3_CLK: R73.2; also elsewhere on the board
SD3_CMD: R72.2; also elsewhere on the board
SD3_D0: R74.2; also elsewhere on the board
SD3_D1: R75.2; also elsewhere on the board
SD3_D2: R70.2; also elsewhere on the board
SD3_D3: R71.2; also elsewhere on the board

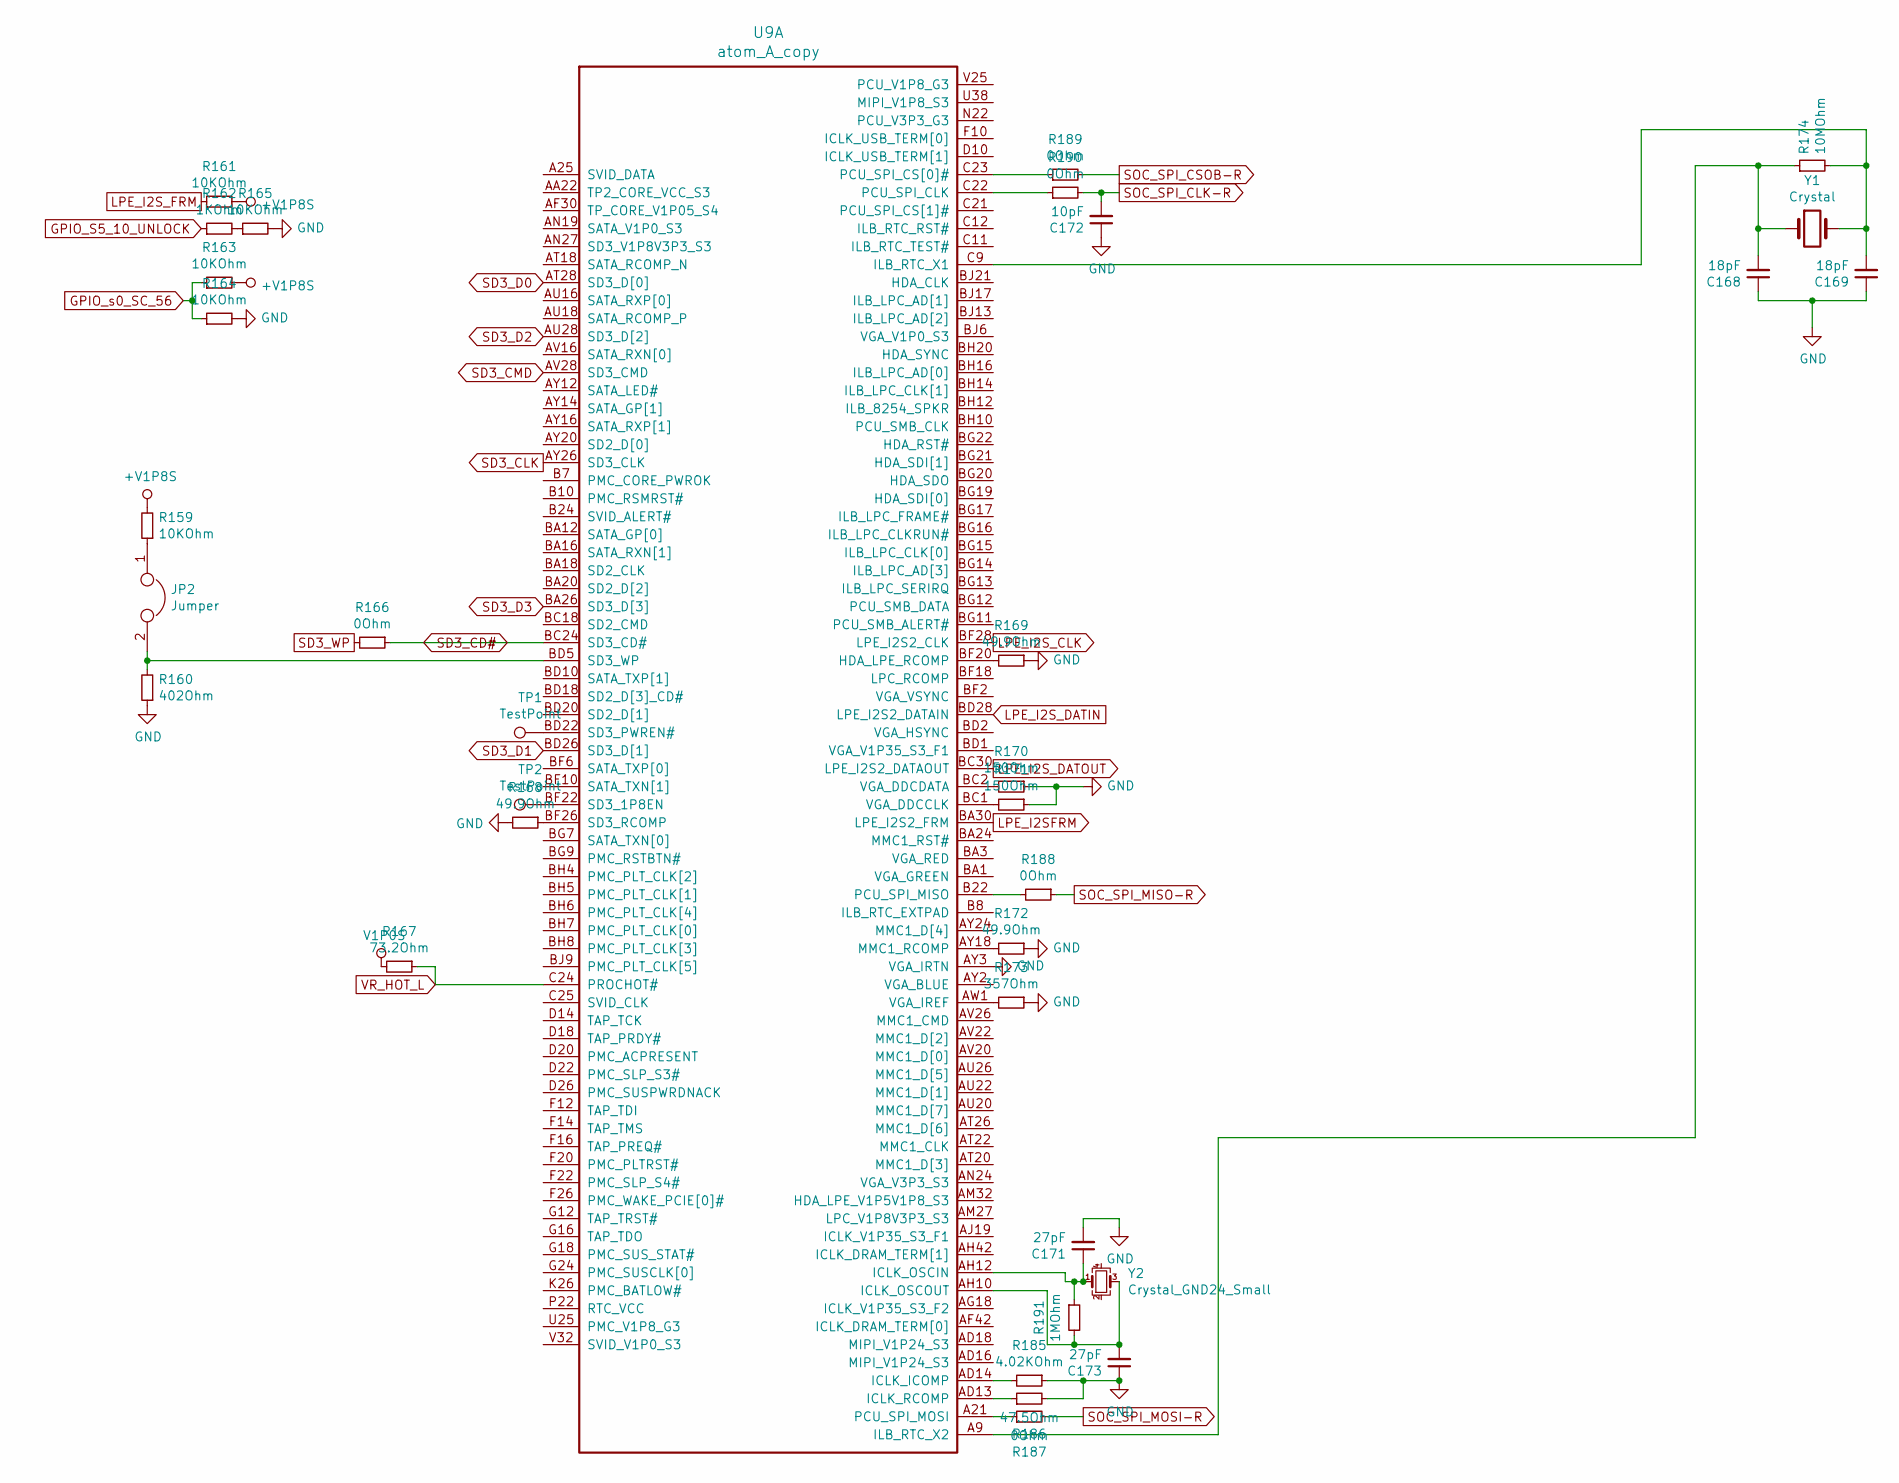
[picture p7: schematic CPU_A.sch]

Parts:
C168, C169: 18pF; C_0603_1608Metric
C171, C173: 27pF; C_0603_1608Metric
C172: 10pF; C_0603_1608Metric
JP2: Jumper; SolderJumper-2_P1.3mm_Open_RoundedPad1.0x1.5mm
R159, R161, R163, R164, R165: 10KOhm; R_0603_1608Metric
R160: 402Ohm; R_0603_1608Metric
R162: 1KOhm; R_0603_1608Metric
R166, R187, R188, R189, R190: 0Ohm; R_0603_1608Metric
R167: 73.2Ohm; R_0603_1608Metric
R168, R169, R172: 49.9Ohm; R_0603_1608Metric
R170, R171: 150Ohm; R_0603_1608Metric
R173: 357Ohm; R_0603_1608Metric
R174: 10MOhm; R_0603_1608Metric
R185: 4.02KOhm; R_0603_1608Metric
R186: 47.5Ohm; R_0603_1608Metric
R191: 1MOhm; R_0603_1608Metric
TP1, TP2: TestPoint; TestPoint_Pad_D2.0mm
U9: atom_A_copy; FCBGA11702
Y1: Crystal; Crystal_SMD_3215-2Pin_3.2x1.5mm
Y2: Crystal_GND24_Small; Crystal_SMD_3225-4Pin_3.2x2.5mm_HandSoldering

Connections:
+V1P8S: R159.2, R161.2, R163.2; also elsewhere on the board
GND: C168.1, C169.1, C171.2, C172.1, C173.1, R160.1, R164.2, R165.2, R168.2, R169.1, R170.1, R171.1, R172.1, R173.1, R185.1, R186.2, U9.AY3 (VGA_IRTN); also elsewhere on the board
GPIO_S5_10_UNLOCK: R162.1
GPIO_s0_SC_56: R163.1, R164.1
LPE_I2SFRM: U9.BA30 (LPE_I2S2_FRM)
LPE_I2S_CLK: U9.BF28 (LPE_I2S2_CLK)
LPE_I2S_DATIN: U9.BD28 (LPE_I2S2_DATAIN)
LPE_I2S_DATOUT: U9.BC30 (LPE_I2S2_DATAOUT)
LPE_I2S_FRM: R161.1
unnamed: C168.2, R174.1, U9.A9 (ILB_RTC_X2), Y1.1
unnamed: C169.2, R174.2, U9.C9 (ILB_RTC_X1), Y1.2
unnamed: C171.1, R191.1, U9.AH12 (ICLK_OSCIN), Y2.1
unnamed: C173.2, R191.2, U9.AH10 (ICLK_OSCOUT), Y2.3
unnamed: JP2.1, R159.1
unnamed: JP2.2, R160.2, U9.BD5 (SD3_WP)
unnamed: R162.2, R165.1
unnamed: R168.1, U9.BF26 (SD3_RCOMP)
unnamed: R169.2, U9.BF20 (HDA_LPE_RCOMP)
unnamed: R170.2, U9.BC2 (VGA_DDCDATA)
unnamed: R171.2, U9.BC1 (VGA_DDCCLK)
unnamed: R172.2, U9.AY18 (MMC1_RCOMP)
unnamed: R173.2, U9.AW1 (VGA_IREF)
unnamed: R185.2, U9.AD14 (ICLK_ICOMP)
unnamed: R186.1, U9.AD13 (ICLK_RCOMP)
unnamed: R187.1, U9.A21 (PCU_SPI_MOSI)
unnamed: R188.2, U9.B22 (PCU_SPI_MISO)
unnamed: R189.1, U9.C23 (PCU_SPI_CS[0]#)
unnamed: R190.1, U9.C22 (PCU_SPI_CLK)
unnamed: TP1.1, U9.BD22 (SD3_PWREN#)
unnamed: TP2.1, U9.BF22 (SD3_1P8EN)
SD3_CD#: R166.1, U9.BC24 (SD3_CD#)
SD3_CLK: U9.AY26 (SD3_CLK); also elsewhere on the board
SD3_CMD: U9.AV28 (SD3_CMD); also elsewhere on the board
SD3_D0: U9.AT28 (SD3_D[0]); also elsewhere on the board
SD3_D1: U9.BD26 (SD3_D[1]); also elsewhere on the board
SD3_D2: U9.AU28 (SD3_D[2]); also elsewhere on the board
SD3_D3: U9.BA26 (SD3_D[3]); also elsewhere on the board
SD3_WP: R166.2
SOC_SPI_CLK-R: C172.2, R190.2; also elsewhere on the board
SOC_SPI_CSOB-R: R189.2
SOC_SPI_MISO-R: R188.1; also elsewhere on the board
SOC_SPI_MOSI-R: R187.2; also elsewhere on the board
V1P05S: R167.2; also elsewhere on the board
VR_HOT_L: R167.1, U9.C24 (PROCHOT#); also elsewhere on the board

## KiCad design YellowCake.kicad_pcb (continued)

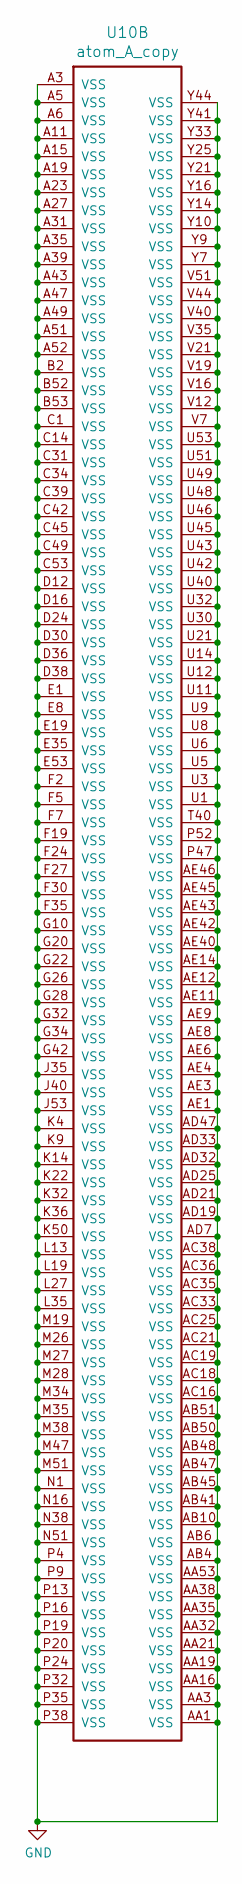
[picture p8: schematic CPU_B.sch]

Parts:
U10: atom_A_copy; FCBGA11702

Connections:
GND: U10.A3 (VSS), U10.A5 (VSS), U10.A6 (VSS), U10.A11 (VSS), U10.A15 (VSS), U10.A19 (VSS), U10.A23 (VSS), U10.A27 (VSS), U10.A31 (VSS), U10.A35 (VSS), U10.A39 (VSS), U10.A43 (VSS), U10.A47 (VSS), U10.A49 (VSS), U10.A51 (VSS), U10.A52 (VSS), U10.AA1 (VSS), U10.AA3 (VSS), U10.AA16 (VSS), U10.AA19 (VSS), U10.AA21 (VSS), U10.AA32 (VSS), U10.AA35 (VSS), U10.AA38 (VSS), U10.AA53 (VSS), U10.AB4 (VSS), U10.AB6 (VSS), U10.AB10 (VSS), U10.AB41 (VSS), U10.AB45 (VSS), U10.AB47 (VSS), U10.AB48 (VSS), U10.AB50 (VSS), U10.AB51 (VSS), U10.AC16 (VSS), U10.AC18 (VSS), U10.AC19 (VSS), U10.AC21 (VSS), U10.AC25 (VSS), U10.AC33 (VSS), U10.AC35 (VSS), U10.AC36 (VSS), U10.AC38 (VSS), U10.AD7 (VSS), U10.AD19 (VSS), U10.AD21 (VSS), U10.AD25 (VSS), U10.AD32 (VSS), U10.AD33 (VSS), U10.AD47 (VSS), U10.AE1 (VSS), U10.AE3 (VSS), U10.AE4 (VSS), U10.AE6 (VSS), U10.AE8 (VSS), U10.AE9 (VSS), U10.AE11 (VSS), U10.AE12 (VSS), U10.AE14 (VSS), U10.AE40 (VSS), U10.AE42 (VSS), U10.AE43 (VSS), U10.AE45 (VSS), U10.AE46 (VSS), U10.B2 (VSS), U10.B52 (VSS), U10.B53 (VSS), U10.C1 (VSS), U10.C14 (VSS), U10.C31 (VSS), U10.C34 (VSS), U10.C39 (VSS), U10.C42 (VSS), U10.C45 (VSS), U10.C49 (VSS), U10.C53 (VSS), U10.D12 (VSS), U10.D16 (VSS), U10.D24 (VSS), U10.D30 (VSS), U10.D36 (VSS), U10.D38 (VSS), U10.E1 (VSS), U10.E8 (VSS), U10.E19 (VSS), U10.E35 (VSS), U10.E53 (VSS), U10.F2 (VSS), U10.F5 (VSS), U10.F7 (VSS), U10.F19 (VSS), U10.F24 (VSS), U10.F27 (VSS), U10.F30 (VSS), U10.F35 (VSS), U10.G10 (VSS), U10.G20 (VSS), U10.G22 (VSS), U10.G26 (VSS), U10.G28 (VSS), U10.G32 (VSS), U10.G34 (VSS), U10.G42 (VSS), U10.J35 (VSS), U10.J40 (VSS), U10.J53 (VSS), U10.K4 (VSS), U10.K9 (VSS), U10.K14 (VSS), U10.K22 (VSS), U10.K32 (VSS), U10.K36 (VSS), U10.K50 (VSS), U10.L13 (VSS), U10.L19 (VSS), U10.L27 (VSS), U10.L35 (VSS), U10.M19 (VSS), U10.M26 (VSS), U10.M27 (VSS), U10.M28 (VSS), U10.M34 (VSS), U10.M35 (VSS), U10.M38 (VSS), U10.M47 (VSS), U10.M51 (VSS), U10.N1 (VSS), U10.N16 (VSS), U10.N38 (VSS), U10.N51 (VSS), U10.P4 (VSS), U10.P9 (VSS), U10.P13 (VSS), U10.P16 (VSS), U10.P19 (VSS), U10.P20 (VSS), U10.P24 (VSS), U10.P32 (VSS), U10.P35 (VSS), U10.P38 (VSS), U10.P47 (VSS), U10.P52 (VSS), U10.T40 (VSS), U10.U1 (VSS), U10.U3 (VSS), U10.U5 (VSS), U10.U6 (VSS), U10.U8 (VSS), U10.U9 (VSS), U10.U11 (VSS), U10.U12 (VSS), U10.U14 (VSS), U10.U21 (VSS), U10.U30 (VSS), U10.U32 (VSS), U10.U40 (VSS), U10.U42 (VSS), U10.U43 (VSS), U10.U45 (VSS), U10.U46 (VSS), U10.U48 (VSS), U10.U49 (VSS), U10.U51 (VSS), U10.U53 (VSS), U10.V7 (VSS), U10.V12 (VSS), U10.V16 (VSS), U10.V19 (VSS), U10.V21 (VSS), U10.V35 (VSS), U10.V40 (VSS), U10.V44 (VSS), U10.V51 (VSS), U10.Y7 (VSS), U10.Y9 (VSS), U10.Y10 (VSS), U10.Y14 (VSS), U10.Y16 (VSS), U10.Y21 (VSS), U10.Y25 (VSS), U10.Y33 (VSS), U10.Y41 (VSS), U10.Y44 (VSS); also elsewhere on the board

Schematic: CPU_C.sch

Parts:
U11: atom_A_copy; FCBGA11702

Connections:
GND: U11.AE48 (VSS), U11.AE50 (VSS), U11.AE51 (VSS), U11.AE53 (VSS), U11.AF10 (VSS), U11.AF12 (VSS), U11.AF25 (VSS), U11.AF32 (VSS), U11.AF47 (VSS), U11.AG16 (VSS), U11.AG25 (VSS), U11.AG36 (VSS), U11.AG38 (VSS), U11.AH4 (VSS), U11.AH6 (VSS), U11.AH7 (VSS), U11.AH9 (VSS), U11.AH41 (VSS), U11.AH45 (VSS), U11.AH47 (VSS), U11.AH48 (VSS), U11.AH50 (VSS), U11.AH51 (VSS), U11.AJ1 (VSS), U11.AJ3 (VSS), U11.AJ16 (VSS), U11.AJ21 (VSS), U11.AJ25 (VSS), U11.AJ27 (VSS), U11.AJ29 (VSS), U11.AJ30 (VSS), U11.AJ32 (VSS), U11.AJ33 (VSS), U11.AJ35 (VSS), U11.AJ38 (VSS), U11.AJ53 (VSS), U11.AK10 (VSS), U11.AK14 (VSS), U11.AK16 (VSS), U11.AK33 (VSS), U11.AK41 (VSS), U11.AK44 (VSS), U11.AM7 (VSS), U11.AM12 (VSS), U11.AM19 (VSS), U11.AM24 (VSS), U11.AM25 (VSS), U11.AM29 (VSS), U11.AM33 (VSS), U11.AM35 (VSS), U11.AM36 (VSS), U11.AM40 (VSS), U11.AM44 (VSS), U11.AM51 (VSS), U11.AN1 (VSS), U11.AN3 (VSS), U11.AN5 (VSS), U11.AN6 (VSS), U11.AN8 (VSS), U11.AN9 (VSS), U11.AN11 (VSS), U11.AN12 (VSS), U11.AN14 (VSS), U11.AN16 (VSSA), U11.AN22 (VSS), U11.AN33 (VSS), U11.AN35 (VSS), U11.AN36 (VSS), U11.AN38 (VSS), U11.AN40 (VSS), U11.AN42 (VSS), U11.AN43 (VSS), U11.AN45 (VSS), U11.AN46 (VSS), U11.AN48 (VSS), U11.AN49 (VSS), U11.AN51 (VSS), U11.AN53 (VSS), U11.AP40 (VSS), U11.AT4 (VSS), U11.AT12 (VSS), U11.AT16 (VSS), U11.AT19 (VSS), U11.AT24 (VSS), U11.AT27 (VSS), U11.AT30 (VSS), U11.AT35 (VSS), U11.AT38 (VSS), U11.AT47 (VSS), U11.AT52 (VSS), U11.AU1 (VSS), U11.AU3 (VSS), U11.AU24 (VSS), U11.AU30 (VSS), U11.AU38 (VSS), U11.AU51 (VSS), U11.AV7 (VSS), U11.AV12 (VSS), U11.AV13 (VSS), U11.AV14 (VSS), U11.AV18 (VSS), U11.AV19 (VSS), U11.AV24 (VSS), U11.AV27 (VSS), U11.AV30 (VSS), U11.AV35 (VSS), U11.AV38 (VSS), U11.AV47 (VSS), U11.AV51 (VSS), U11.AW3 (VSS), U11.AW13 (VSS), U11.AW19 (VSS), U11.AW27 (VSS), U11.AW35 (VSS), U11.AY4 (VSS), U11.AY9 (VSS), U11.AY10 (VSS), U11.AY22 (VSS), U11.AY32 (VSS), U11.AY36 (VSS), U11.AY50 (VSS), U11.BA14 (VSS), U11.BA19 (VSS), U11.BA22 (VSS), U11.BA27 (VSS), U11.BA32 (VSS), U11.BA35 (VSS), U11.BA40 (VSS), U11.BA53 (VSS), U11.BB19 (VSS), U11.BB27 (VSS), U11.BB35 (VSS), U11.BC20 (VSS), U11.BC22 (VSS), U11.BC26 (VSS), U11.BC28 (VSS), U11.BC32 (VSS), U11.BC34 (VSS), U11.BC42 (VSS), U11.BD19 (VSS), U11.BD24 (VSS), U11.BD27 (VSS), U11.BD30 (VSS), U11.BD35 (VSS), U11.BE1 (VSS), U11.BE2 (VSS), U11.BE8 (VSS), U11.BE19 (VSS), U11.BE35 (VSS), U11.BE53 (VSS), U11.BF4 (VSS), U11.BF12 (VSS), U11.BF16 (VSS), U11.BF24 (VSS), U11.BF30 (VSS), U11.BF36 (VSS), U11.BF38 (VSS), U11.BG1 (VSS), U11.BG31 (VSS), U11.BG34 (VSS), U11.BG39 (VSS), U11.BG42 (VSS), U11.BG45 (VSS), U11.BG49 (VSS), U11.BG53 (VSS), U11.BH1 (VSS), U11.BH2 (VSS), U11.BH52 (VSS), U11.BH53 (VSS), U11.BJ2 (VSS), U11.BJ3 (VSS), U11.BJ5 (VSS), U11.BJ7 (VSS), U11.BJ11 (VSS), U11.BJ15 (VSS), U11.BJ19 (VSS), U11.BJ23 (VSS), U11.BJ27 (VSS), U11.BJ31 (VSS), U11.BJ35 (VSS), U11.BJ39 (VSS), U11.BJ43 (VSS), U11.BJ47 (VSS), U11.BJ49 (VSS), U11.BJ51 (VSS), U11.BJ52 (VSS); also elsewhere on the board

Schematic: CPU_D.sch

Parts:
U12: atom_A_copy; FCBGA11702

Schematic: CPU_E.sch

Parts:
U13: atom_A_copy; FCBGA11702

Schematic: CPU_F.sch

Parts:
U14: atom_A_copy; FCBGA11702

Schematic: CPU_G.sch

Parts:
U15: atom_A_copy; FCBGA11702

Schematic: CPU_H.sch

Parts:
U16: atom_A_copy; FCBGA11702

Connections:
SOC_GPIO_S5_0: U16.B18 (GPIO_S5[00])
SOC_GPIO_S5_1: U16.B16 (GPIO_S5[01])
SOC_GPIO_S5_2: U16.C18 (GPIO_S5[02])

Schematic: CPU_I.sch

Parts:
R175, R176, R177, R178, R179, R180: 0Ohm; R_0603_1608Metric
R181: 10KOhm; R_0603_1608Metric
TP3: TestPoint; TestPoint_Pad_D2.0mm
U17: atom_A_copy; FCBGA11702

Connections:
GND: R175.2, R176.2, R177.2, R178.2, R179.2, R180.2, R181.1; also elsewhere on the board
unnamed: R175.1, U17.AH2 (RSVD_GND[3])
unnamed: R176.1, U17.AH3 (RSVD_GND[2])
unnamed: R177.1, U17.AM2 (RSVD_GND[1])
unnamed: R178.1, U17.AM3 (RSVD_GND[0])
unnamed: R179.1, U17.BB5 (RSVD_GND[6])
unnamed: R180.1, U17.BB7 (RSVD_GND[7])
unnamed: R181.2, U17.A29 (RESERVED)
unnamed: TP3.1, U17.B30 (RESERVED)

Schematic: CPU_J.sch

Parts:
C170: 0.1uF; C_0603_1608Metric
R182: 2.2KOhm; R_0603_1608Metric
R183: 420Ohm; R_0603_1608Metric
U18: atom_A_copy; FCBGA11702
U33: SN74LVC1G14DBVR

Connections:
+V1P8S: C170.1, U33.5 (VCC); also elsewhere on the board
GND: C170.2, R182.1, U18.G30 (DDI1_DDCCLK), U18.K30 (DDI1_HPD), U33.3 (GND); also elsewhere on the board
HDMI_CLK_DN: U18.AP2 (DDI0_TXN[3]); also elsewhere on the board
HDMI_CLK_DP: U18.AP3 (DDI0_TXP[3]); also elsewhere on the board
HDMI_DDCCLK: U18.C27 (DDI0_BKLTEN); also elsewhere on the board
HDMI_DDCDAT: U18.C26 (DDI0_DDCDATA); also elsewhere on the board
HDMI_HPD: U33.2 (A)
HDMI_TX0_DN: U18.AR1 (DDI0_TXN[2]); also elsewhere on the board
HDMI_TX0_DP: U18.AR3 (DDI0_TXP[2]); also elsewhere on the board
HDMI_TX1_DN: U18.AT3 (DDI0_TXN[1]); also elsewhere on the board
HDMI_TX1_DP: U18.AT2 (DDI0_TXP[1]); also elsewhere on the board
HDMI_TX2_DN: U18.AV2 (DDI0_TXN[0]); also elsewhere on the board
HDMI_TX2_DP: U18.AV3 (DDI0_TXP[0]); also elsewhere on the board
unnamed: R182.2, U18.P30 (DDI1_DDCDATA)
unnamed: R183.1, U18.AK12 (DDI_RCOMP_P)
unnamed: R183.2, U18.AK13 (DDI_RCOMP_N)
unnamed: U18.D27 (DDI0_HPD), U33.4 (Y)

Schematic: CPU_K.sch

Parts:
U19: atom_A_copy; FCBGA11702

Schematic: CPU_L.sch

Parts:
R184: 150Ohm; R_0603_1608Metric
U20: atom_L; FCBGA11702

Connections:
GND: R184.2; also elsewhere on the board
unnamed: R184.1, U20.P14 (MCSI_RCOMP)

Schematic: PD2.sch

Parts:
C66, C69, C71, C78, C79, C80, C81, C82, C83, C84, C85, C86, C94, C95: 0.1uF; C_0603_1608Metric
C67, C68, C70, C73, C74, C87, C88, C90, C92, C93: 22uF; C_0603_1608Metric
C72, C77: 1.0uF; C_0603_1608Metric
C75: 0.22uF; C_0603_1608Metric
C76, C89, C91: 10uF; C_0603_1608Metric; Rating 16V
D2, D3: BAV99S; SOT-363_SC-70-6
J6: Conn_Coaxial_Power; BarrelJack_Horizontal
L11, L12, L13, L14: FB_120R_3A; L_0603_1608Metric
L15: PIND-2.2U-8A; L_0603_1608Metric
R82, R84: 499KOhm; R_0603_1608Metric
R83: 2.2Ohms; R_0603_1608Metric
R85, R87: 100KOhm; R_0603_1608Metric
R86: 4.7Ohm; R_0603_1608Metric
R88: 33Ohm; R_0603_1608Metric
R89: 2.2KOhm; R_0603_1608Metric
R90, R91: 1KOhm; R_0603_1608Metric
U21: NB670; VQFN_EP
U22: IRF9321; SO-8_5.3x6.2mm_P1.27mm
U23: NCT3012S; SOIC-8_3.9x4.9mm_P1.27mm

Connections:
5VSB_CTRL: R90.1, U23.8 (SYS5VSB_OFF); also elsewhere on the board
+10V: C85.2, D3.2 (K2); also elsewhere on the board
+PS_3VSB: C81.1, C87.1, C88.1, C90.1, C92.1, C93.1, C94.1, L15.2, R91.2, U21.7 (VOUT); also elsewhere on the board
+PS_3VSB_PG: R85.2, U21.4 (PG); also elsewhere on the board
+PS_5VSB: C78.2, C84.1, C86.1, C89.1, C91.1, C95.1, D2.1 (A1), L11.1, L12.1, R89.2, R90.2, U22.5 (D), U22.6 (D), U22.7 (D), U22.8 (D), U23.2 (VSB); also elsewhere on the board
DDR_SMB_CLK: U23.6 (SCLK)
DDR_SMB_DATA: U23.5 (SDA)
FP_PWRBTN: R88.2; also elsewhere on the board
GND: C66.2, C67.2, C68.2, C69.2, C70.2, C71.2, C72.2, C73.2, C74.2, C76.2, C77.2, C78.1, C80.1, C81.2, C84.2, C85.1, C86.2, C87.2, C88.2, C89.2, C90.2, C91.2, C92.2, C93.2, C94.2, C95.2, J6.2 (Ext), R82.2, R87.1, U21.2 (PGND), U21.14 (AGND); also elsewhere on the board
unnamed: C66.1, C69.1, J6.1 (In), L13.2, L14.2, R83.1
unnamed: C67.1, C68.1, C70.1, C73.1, C74.1, L11.2, L12.2, R84.1, U21.1 (VIN)
unnamed: C71.1, R82.1, R84.2, U21.13 (EN)
unnamed: C72.1, R83.2
unnamed: C75.1, L13.1, L14.1, U22.1 (S), U22.2 (S), U22.3 (S)
unnamed: C75.2, R87.2, U22.4 (G)
unnamed: C76.1, U21.6 (LDO)
unnamed: C77.1, R85.1, U21.11 (VCC)
unnamed: C79.1, D2.6 (K3A4)
unnamed: C79.2, C83.2, U21.5 (CLK)
unnamed: C80.2, D2.2 (K2), D3.1 (A1)
unnamed: C82.1, R86.1
unnamed: C82.2, L15.1, U21.8 (SW1), U21.9 (SW2), U21.15 (SW3), U21.16 (SW4)
unnamed: C83.1, D3.6 (K3A4)
unnamed: R86.2, U21.10 (BST)
unnamed: R88.1, U23.3 (PS_IN#)
unnamed: R89.1, U23.1 (DeepS5_Sel)
PS_OUT_L: R91.1, U23.7 (PS_OUT#)
SLP_S4_L: U23.4 (SLP_S5#)

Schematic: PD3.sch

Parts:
C96, C98, C100, C119: 1uF; C_0603_1608Metric
C97, C99, C102, C103: 10uF; C_0603_1608Metric
C101: 4700PF; C_0603_1608Metric
C104, C105: 2.2uF; C_0603_1608Metric
C106, C107, C108, C115: 22pF; C_0603_1608Metric
C109: 27pF; C_0603_1608Metric
C110, C112, C114, C116, C118: 10uF; C_0603_1608Metric; Rating 16V
C111, C113: 0.1uF; C_0603_1608Metric
C117: 1.0uF; C_0603_1608Metric
D4, D8: BAT54A; SOT-23
D5, D6: APTR3216-VFX; LED_1206_3216Metric
D7: D5V0L1B2LP-7B; D_01005_0402Metric
H1, H2, H3, H4: MountingHole_Pad; MountingHole_3.2mm_M3_Pad
JP1: Jumper; SolderJumper-2_P1.3mm_Open_RoundedPad1.0x1.5mm
L16: INDUCTOR; L_0603_1608Metric
Q1, Q2, Q4, Q5, Q6: 2N7002K; SOT-23
Q3: MMBT3904; SOT-23
Q7, Q8: MBT3904DW1; SOT-363_SC-70-6
R92, R93: 10KOhm; R_0603_1608Metric
R94: 1KOhm; R_0603_1608Metric
R95, R97, R100: 100KOhm; R_0603_1608Metric
R96, R98: RQ3E180GNTB
R99: 33KOhm; R_0603_1608Metric
R101: 200KOhm; R_0603_1608Metric
R102, R103, R119: RQ5E035ATTCL
R111: 1Ohm; R_0603_1608Metric
R112: 148Ohm; R_0603_1608Metric
R113: 146Ohm; R_0603_1608Metric
R114, R115: 40.2KOhm; R_0603_1608Metric
R116: 1kOhm; R_0603_1608Metric
R117, R123: 10kOhm; R_0603_1608Metric
R118, R120, R121: 4.7kOhm; R_0603_1608Metric
R122: 0Ohm; R_0603_1608Metric
R124: 10Ohm; R_0603_1608Metric
R125: 200kOhm; R_0603_1608Metric
R126, R127: 20kOhm; R_0603_1608Metric
SW1: SW_Push; SW_SPST_TL3342
U25: APL5912KAC; HTSOP-8-1EP_3.9x4.9mm_P1.27mm_EP2.4x3.2mm

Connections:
1P5V_EN_B: Q7.5 (B2), Q7.6 (C1), R120.1
1P8V_EN: Q7.3 (C2), R121.1; also elsewhere on the board
5VSB_CTRL: Q1.1 (G), R93.2; also elsewhere on the board
+3VSB: C99.1, R98.1 (2), R98.2 (1), R98.3, R103.3 (D); also elsewhere on the board
+5VSB: C97.1, C101.1, Q6.3 (D), R96.1 (2), R96.2 (1), R96.3, R100.2, R101.1, R102.3 (D), R103.2 (G), R120.2; also elsewhere on the board
+10V: R95.1, R97.1, R99.1, R100.1; also elsewhere on the board
+PS_3VSB: R98.5, R98.6, R98.7, R98.8, R126.2; also elsewhere on the board
+PS_3VSB_PG: D4.1; also elsewhere on the board
+PS_5VSB: C104.1, D5.2 (A), R94.2, R96.5, R96.6, R96.7, R96.8, R118.1; also elsewhere on the board
+V1P0A_PWRGD: D8.2; also elsewhere on the board
+V1P8A: R92.2; also elsewhere on the board
+V1P8S: R125.1; also elsewhere on the board
+VDIMM: C112.1, C114.1, R119.3 (D), U25.5 (VIN), U25.9 (VIN)
FP_PWRBTN: C113.1, D7.1 (K), JP1.2, R118.2, SW1.1; also elsewhere on the board
GND: C96.2, C97.2, C98.2, C99.2, C100.2, C101.2, C102.2, C103.2, C104.2, C105.2, C106.2, C107.2, C108.2, C110.2, C111.2, C112.2, C113.2, C114.2, C115.2, C116.1, C117.1, C118.1, C119.1, D7.2 (A), JP1.1, Q1.2 (S), Q2.2 (S), Q3.2 (E), Q4.2 (S), Q5.2 (S), Q6.2 (S), Q7.1 (E1), Q7.4 (E2), Q8.1 (E1), Q8.4 (E2), R101.2, R111.2, R112.1, R113.1, R114.2, SW1.2, U25.1 (GND); also elsewhere on the board
unnamed: C96.1, Q2.1 (G), R93.1
unnamed: C98.1, Q2.3 (D), R95.2, R96.4
unnamed: C100.1, Q4.3 (D), R97.2, R98.4
unnamed: C109.2, R115.2, U25.2 (FB)
unnamed: C111.1, R116.1, R119.2 (G)
unnamed: C117.2, R124.2, U25.6 (VCNTL)
unnamed: C119.2, D8.3, Q8.2 (B1), R125.2
unnamed: D4.2, Q3.3 (C), Q4.1 (G), R94.1
unnamed: D5.1 (K), R112.2
unnamed: D6.1 (K), R113.2
unnamed: H1.1, H2.1, H3.1, H4.1, R111.1
unnamed: Q1.3 (D), Q3.1 (B), R92.1
unnamed: Q5.3 (D), Q6.1 (G), R99.2
unnamed: Q7.2 (B1), R117.2
unnamed: Q8.5 (B2), Q8.6 (C1), R126.1
unnamed: R122.1, U25.8 (EN)
unnamed: R123.1, U25.7 (POK)
PMC_RSMRST: D4.3
SLP_S3_L: D8.1, Q5.1 (G)
SYS_PWRGD: Q8.3 (C2), R127.2
V1P0S_PG: R116.2
V1P05S: C106.1, C107.1, C108.1, C109.1, C110.1, R114.1, R115.1, U25.3 (VOUT), U25.4 (VOUT); also elsewhere on the board
V1P35S: C115.1, C116.2, R117.1, R119.1 (S)
VCC: C102.1, C105.1, D6.2 (A), R102.1 (S), R121.2, R123.2, R124.1; also elsewhere on the board
VCC3: C103.1, L16.1, R103.1 (S), R127.1
VCC3S: C118.2, L16.2
VCORE_GFX_PG: R122.2; also elsewhere on the board

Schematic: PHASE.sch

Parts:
C120, C121: 0.1uF; C_0603_1608Metric
C122, C123, C124, C125, C128, C129, C130, C131, C132, C133, C137, C138, C139, C140, C141, C142, C143, C144, C145, C146, C147, C148: 22uF; C_0603_1608Metric
C126, C127: 2200pF; C_0603_1608Metric
C134, C135, C136: 330uF; CP_EIA-7343-20_Kemet-V
L17, L18: FB_120R_3A; L_0603_1608Metric
L19, L20: ACM2012-900-2P-T
L21, L22: 0.33uH; L_0603_1608Metric
R128, R129, R130, R131, R140, R141: 0Ohm; R_0603_1608Metric
R132, R133: 10KOhm; R_0603_1608Metric
R134, R137: 2.2Ohm; R_0603_1608Metric
R135, R138: 1KOhm; R_0603_1608Metric
R136, R139: 1Ohm; R_0603_1608Metric
U26, U27: FDMS7602S; TRANS_FDMD8530

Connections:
+5VSB: C120.1, L17.1, L18.1; also elsewhere on the board
+5VSB_SW: C121.1, C122.1, C123.1, C124.1, C125.1, C128.1, C129.1, C130.1, C131.1, C132.1, C133.1, L17.2, L18.2, U26.2 (D1), U26.3 (D1), U26.4 (D1), U26.9 (D1), U27.2 (D1), U27.3 (D1), U27.4 (D1), U27.9 (D1); also elsewhere on the board
+VCORE: C135.1, L19.3, L21.2, R140.1; also elsewhere on the board
+VGFX: C134.1, C136.1, L20.3, L22.2, R141.1; also elsewhere on the board
GND: C120.2, C121.2, C122.2, C123.2, C124.2, C125.2, C126.2, C127.2, C128.2, C129.2, C130.2, C131.2, C132.2, C133.2, C134.2, C135.2, C136.2, C137.2, C138.2, C139.2, C140.2, C141.2, C142.2, C143.2, C144.2, C145.2, C146.2, C147.2, C148.2, U26.5 (S2), U26.6 (S2), U26.7 (S2), U27.5 (S2), U27.6 (S2), U27.7 (S2); also elsewhere on the board
LGATE1: R128.1; also elsewhere on the board
LGATEG: R130.1; also elsewhere on the board
unnamed: C126.1, R134.2
unnamed: C127.1, R137.2
unnamed: C137.1, C139.1, C141.1, C143.1, C145.1, R140.2
unnamed: C138.1, C140.1, C142.1, C144.1, C146.1, C147.1, C148.1, R141.2
unnamed: L19.1, R135.2
unnamed: L19.2, R136.2
unnamed: L20.1, R138.2
unnamed: L20.2, R139.2
unnamed: R128.2, U26.8 (G2)
unnamed: R129.2, R132.2, U26.1 (G1)
unnamed: R130.2, U27.8 (G2)
unnamed: R131.2, R133.2, U27.1 (G1)
PHASE1: L19.4, L21.1, R132.1, R134.1, U26.10 (PHASE); also elsewhere on the board
PHASEG: L20.4, L22.1, R133.1, R137.1, U27.10 (PHASE); also elsewhere on the board
UGATE1: R129.1; also elsewhere on the board
UGATEG: R131.1; also elsewhere on the board
VSUMN: R136.1; also elsewhere on the board
VSUMNG: R139.1; also elsewhere on the board
VSUMP: R135.1; also elsewhere on the board
VSUMPG: R138.1; also elsewhere on the board

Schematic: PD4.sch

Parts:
C149, C151, C156, C157, C158, C159, C163: 0.1uF; C_0603_1608Metric
C150, C153: 22uF; C_0603_1608Metric
C152, C160, C161, C162, C165: 10uF; C_0603_1608Metric
C154, C155: 150pF; C_0603_1608Metric
C164: 22pF; C_0603_1608Metric
R142: 6.04KOhm; R_0603_1608Metric
R143: 23.7KOhm; R_0603_1608Metric
R144, R153, R154: 12.1KOhm; R_0603_1608Metric
R145: 9.53KOhm; R_0603_1608Metric
R146: 10KOhm; R_0603_1608Metric
R147, R148, R149, R151: 4.7KOhm; R_0603_1608Metric
R150, R152: 0Ohm; R_0603_1608Metric
U28, U29: APL5933; HTSOP-8-1EP_3.9x4.9mm_P1.27mm_EP2.4x3.2mm
U30: NCP606MN18T2G

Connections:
1P8V_EN: R150.2; also elsewhere on the board
+5VSB: R148.2; also elsewhere on the board
+PS_3VSB: C156.1, C157.1, C160.1, C161.1, C162.2, R149.1, U28.3 (VIN), U28.4 (VCNTL), U29.3 (VIN), U29.4 (VCNTL), U30.1 (VIN), U30.6 (VIN); also elsewhere on the board
+V1P0A: C149.2, C150.1, C154.2, R142.2, U28.6 (VOUT)
+V1P0A_PWRGD: R152.2; also elsewhere on the board
+V1P8A: C164.1, C165.2, R153.1, U30.4 (VOUT); also elsewhere on the board
+V1P8S: C151.2, C152.2, C153.1, C155.2, R144.2, R151.1, U29.6 (VOUT); also elsewhere on the board
GND: C149.1, C150.2, C151.1, C152.1, C153.2, C156.2, C157.2, C158.2, C159.2, C160.2, C161.2, C162.1, C163.2, C165.1, R143.2, R145.2, R146.1, R147.1, R154.2, U28.8 (GND), U28.9 (GND), U29.8 (GND), U29.9 (GND), U30.2 (GND), U30.7 (EPAD); also elsewhere on the board
unnamed: C154.1, R142.1, R143.1, U28.7 (FB)
unnamed: C155.1, R144.1, R145.1, U29.7 (FB)
unnamed: C158.1, R146.2, R148.1, U28.2 (EN)
unnamed: C159.1, R147.2, R150.1, U29.2 (EN)
unnamed: C163.1, R152.1, U30.3 (EN)
unnamed: C164.2, R153.2, R154.1, U30.5 (SENSE)
unnamed: R149.2, U28.1 (POK)
unnamed: R151.2, U29.1 (POK)

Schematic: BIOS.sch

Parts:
C166: 0.1uF; C_0603_1608Metric
C167: 1.0uF; C_0603_1608Metric
D9: BAT54C; SOT-23
J7: Conn_01x08_Male; PinHeader_1x08_P1.00mm_Vertical_SMD_Pin1Left
Q9: BSS138; SOT-23
R155, R156, R157, R158: 10KOhm; R_0603_1608Metric
U31: TS3A27518ERTWR
U32: 25LCxxx; SOIC-8_3.9x4.9mm_P1.27mm

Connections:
+3VSB: D9.1, J7.8; also elsewhere on the board
+V1P8A: Q9.2 (S); also elsewhere on the board
DDP_1V8: C166.1, C167.1, J7.1, Q9.3 (D), R155.2, R156.2, R157.2, R158.1, U31.5 (V+), U32.8 (VCC)
GND: C166.2, C167.2, J7.2, U31.2 (GND), U31.7 (COM5), U31.9 (COM6), U31.17 (*EN), U32.4 (GND); also elsewhere on the board
unnamed: D9.3, Q9.1 (G), U31.11 (IN2), U31.21 (IN1)
unnamed: J7.3, R158.2, U31.18 (NC4)
unnamed: J7.4, U31.23 (NC1)
unnamed: J7.5, U31.20 (NC3)
unnamed: J7.6, U31.22 (NC2)
unnamed: R155.1, U31.6 (COM4), U32.1 (~CS)
unnamed: U31.1 (COM1), U32.6 (SCK)
unnamed: U31.3 (COM2), U32.5 (MOSI)
unnamed: U31.4 (COM3), U32.2 (MISO)
SOC_SPI_CLK-R: U31.8 (NO1); also elsewhere on the board
SOC_SPI_CS0B-R: U31.14 (NO4)
SOC_SPI_MISO-R: U31.12 (NO3); also elsewhere on the board
SOC_SPI_MOSI-R: U31.10 (NO2); also elsewhere on the board
SPI_HOLD: R156.1, U32.7 (~HOLD)
SPI_WP: R157.1, U32.3 (~WP)

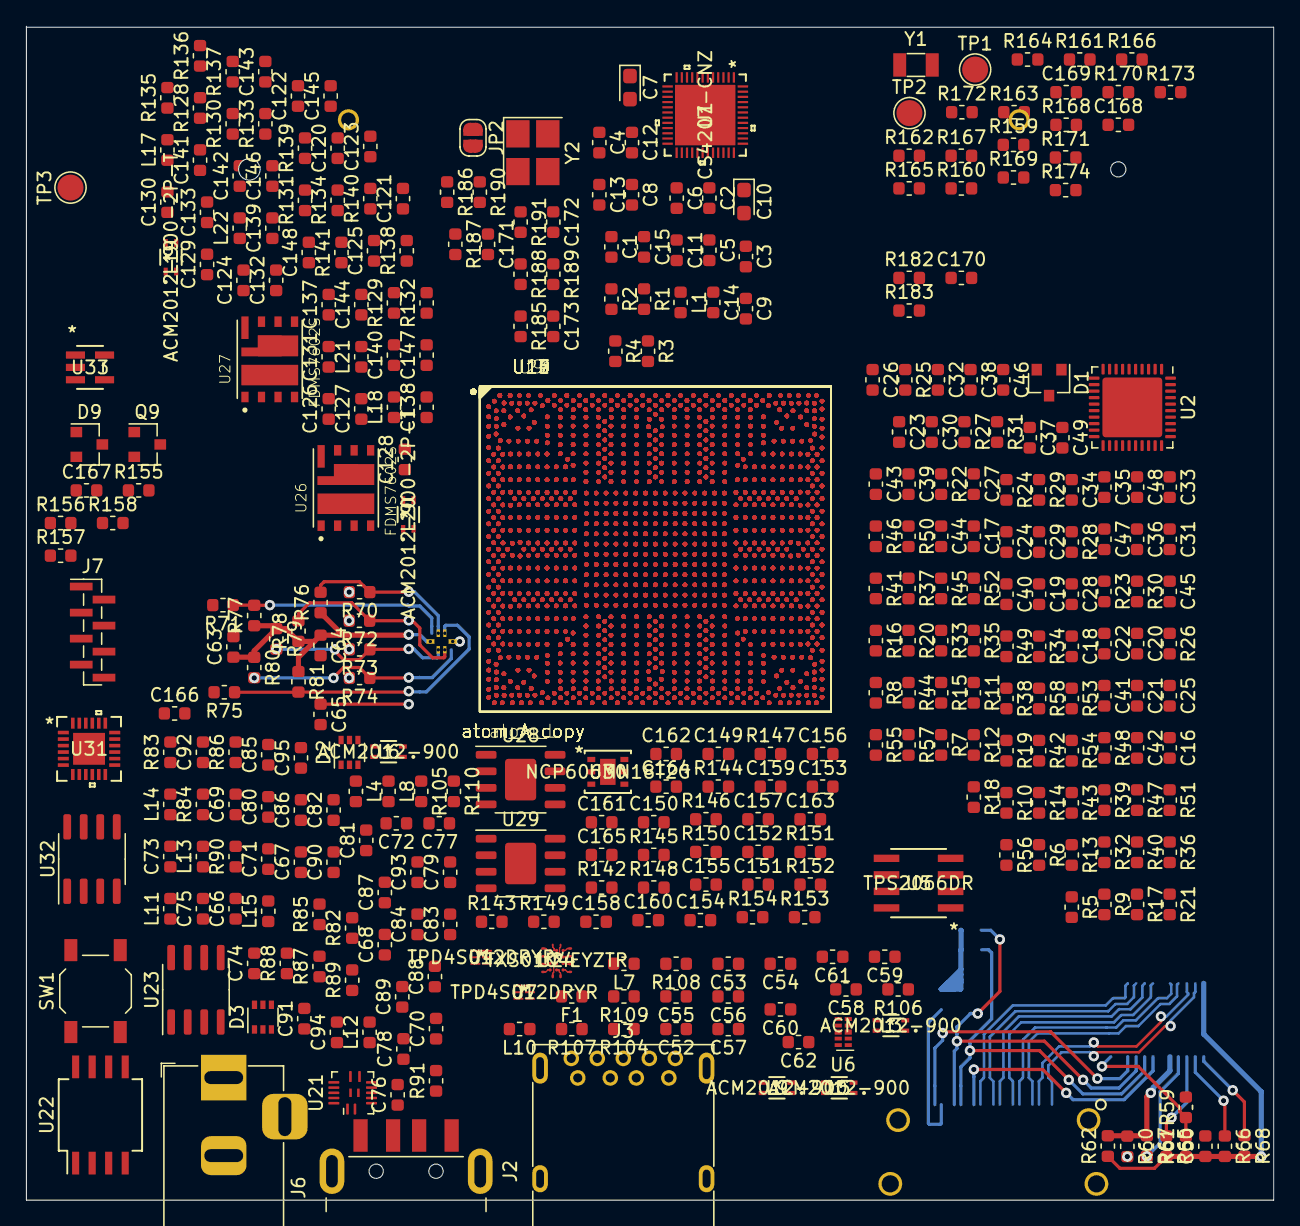
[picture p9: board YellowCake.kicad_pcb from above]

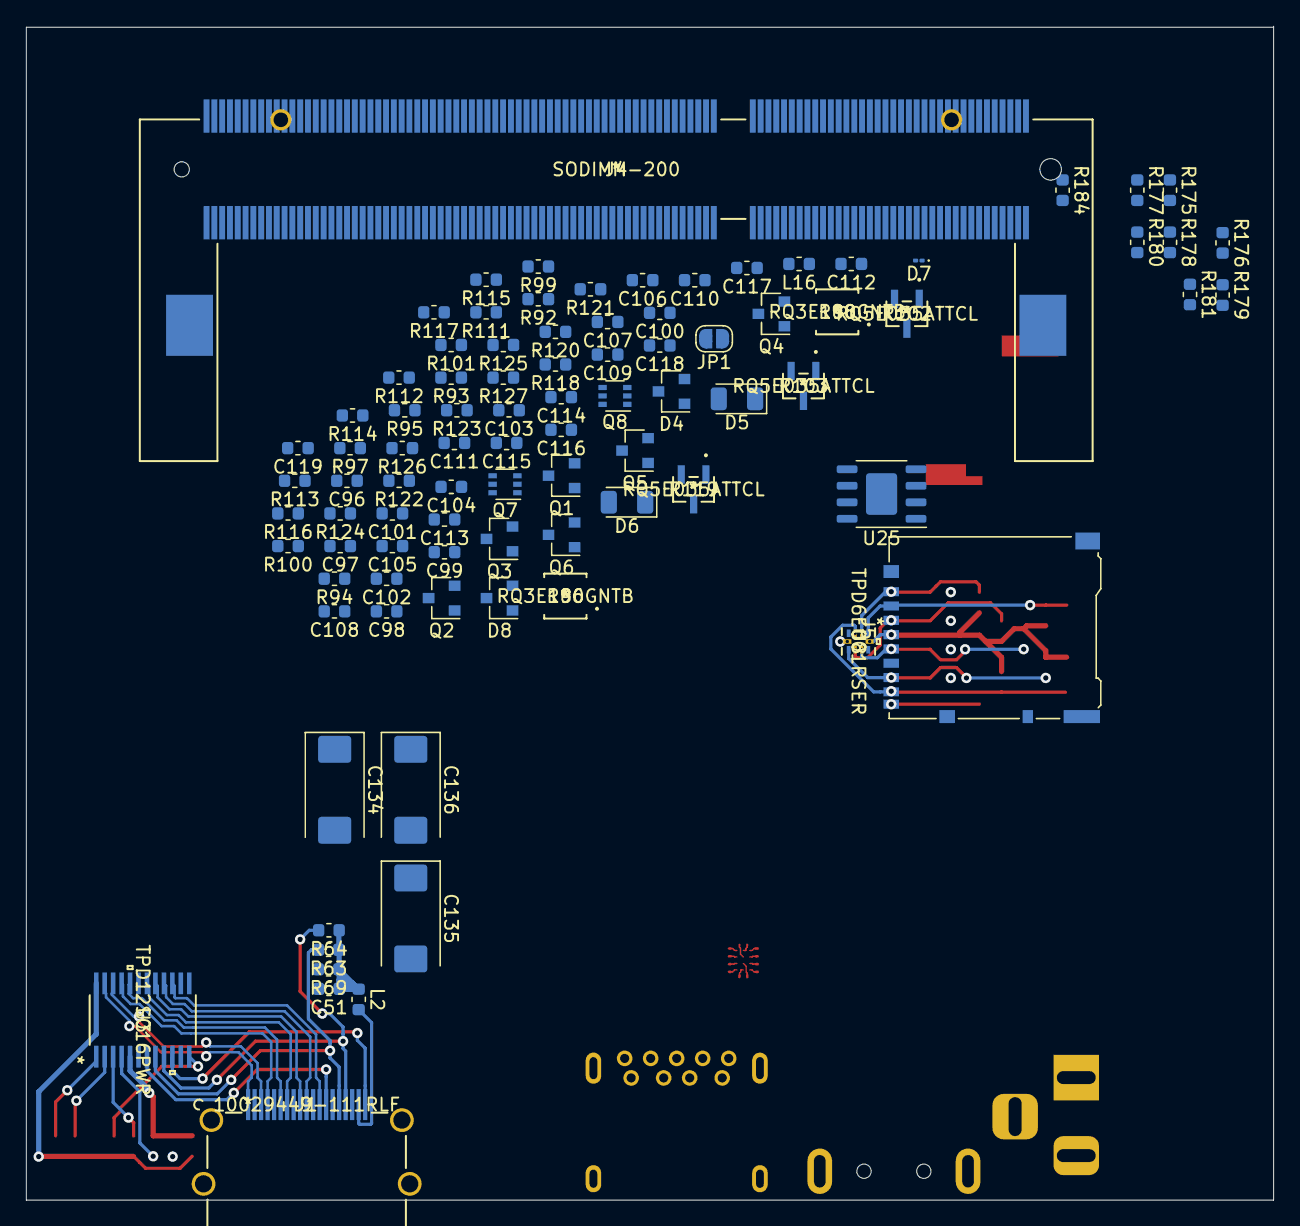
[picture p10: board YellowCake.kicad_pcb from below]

Board: 4 copper layers, 95.9 x 90.2 mm, 453 parts (90 on the bottom side), 264 nets.

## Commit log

2019-05-24 added kicad project
    [YellowCake.kicad_pcb, YellowCake.sch]
2019-10-01 started power supply and DAC circuitry
    [DAC.sch, PD.sch, YellowCake.kicad_pcb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]
2019-10-02 splitting cpu
    [tabula-atom-pintableA.csv, tabula-atom-pintableB.csv, tabula-atom-pintable_clean.csv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]
2019-10-02 added schematic plot
2019-10-09 rest of power controller
    [DAC.sch, PD.sch]
2019-10-16 worked on HDMI and paper
    [DAC.sch, HDMI.sch, PD.sch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]
2019-10-23 finished SDCARD
    [DAC.sch, HDMI.sch, MEM.sch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]
2019-10-28 split cpu and created more power schema
    [CPU_A.sch, CPU_B.sch, CPU_C.sch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]
2019-11-05 added bom
    [YellowCake_bom.csv]
2019-11-07 finishing schematic
    [CPU_A.sch, CPU_B.sch, CPU_C.sch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]
2019-11-08 finished fixes
    [CPU_A.sch, CPU_B.sch, CPU_C.sch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]
2019-11-11 Power done
    [APL5912KAC.csv, APL5933.csv, CPU_A.sch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]
2019-11-12 Finished all except RAM and CPU
    [BIOS.sch, CPU_A.sch, CPU_B.sch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]
2019-11-13 fixed fanout
    [YellowCake.kicad_pcb]
2019-11-18 first gbrs
    [CPU_A.sch, CPU_B.sch, CPU_C.sch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]

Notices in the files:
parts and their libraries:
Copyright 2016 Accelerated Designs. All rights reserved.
